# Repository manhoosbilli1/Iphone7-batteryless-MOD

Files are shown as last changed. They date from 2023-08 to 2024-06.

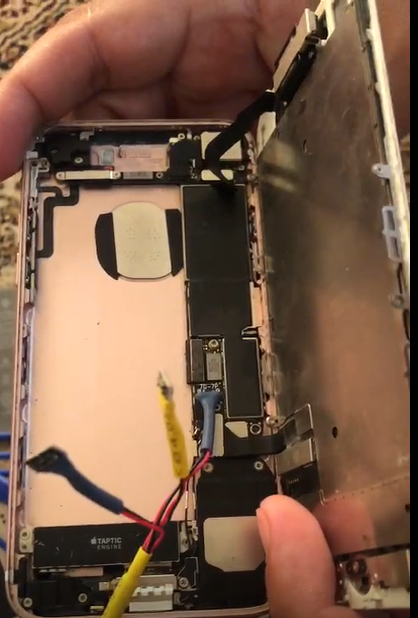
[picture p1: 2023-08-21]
ll.PNG

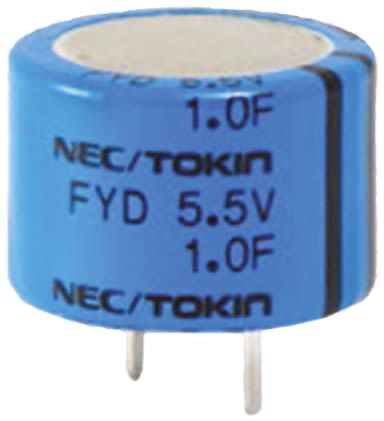
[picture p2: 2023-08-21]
R7897949-01.jpg

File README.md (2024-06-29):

# Iphone7-batteryless-MOD
On going research project into finding a way to use the iphone 7 without a battery like many other smart phones and laptops can be used. 

# Intro
I'm trying to modify iPhone 7 to be able to use without a battery. It's been done before on iPhone 4 successfully and I've seen some people achieve this with iPhone 6. but not iPhone 7 yet. the goal is to revive the old iPhone we have sitting around.

# Problems 
Knowing Apple the thought never crossed my mind that it would as simple as connecting power to the power connector. I was always expecting some kind of logic to be going on behind the scenes. I tried the usual methods of turning on any other android phones but they did not work. 

here is a demo of the current condition of project, [demo](https://youtube.com/shorts/5xmpZtYP9cs?feature=share)

# What I've tried
## Connected power with iPhone battery connector
4.2V line on the battery connector through a stable bench power supply. never turned on. obviously battery was removed at this point. 

## took out the battery protection circuit 
inside the battery and gave it a range of voltage 3.7-4.2V on the terminals where battery is usually attached. never turned on. 

## Used [iboot](https://www.amazon.com/Mechanic-Android-Control-Motherboard-Activation/dp/B07D37CWW3) max+ 

(inspired by qianli ipower max pro (discontinued now [ipower-link](https://www.amazon.com/-/es/Ipower-Pro-Max-reparaci%C3%B3n-compatibles/dp/B0946PBCHP)), it turned on but turns off after 2 minutes. doesn't seem to be a timed event as when computation need increases it turns off. made me think that the device might not be able to provide the surge current it needs compared to when using a battery so, 
[iboot connected to iphone 7][1]
[iboot modul][2]

## added 5V 1F cap across the battery connector with iboot max+ 
similar behaviour as before. turns of after around 2 minutes or before. restarts and so on. no luck 

## Thought to simulate battery while plugged in 
Connected  iboot max+ to iphone and connected charging cable to it's port. the iboot started making noise which made me think that iboot might not expect a reverse current since the battery  connnector also charges it. so that didn't work. 

# Conclusions up till this point 
- there is no circuitry inside a battery anymore so the phones lets iboot max+ power it on and keep it working for a few minutes but it seems like there's a certain communication going on between the battery and the phone. 
- Since it's just a simple battery seems like it's either expecting a certain resistance on the power lines
- Or some kind of response after it uses some of the power from the battery

Nothing else is coming to mind now, i do not have an oscilloscope right now to check the boot power sequence from the battery, though i think that might be helpful. 

  [1]: https://i.stack.imgur.com/8uuAC.png
  [2]: https://i.stack.imgur.com/W1e5v.png

# 8/15/2023 Thoughts 
I am now certain that the battery is designed in a way as to signal the circuit to let it know "hey i'm from apple" usually batteries of samsung and other brands are recognized when the resistance on the power line is of a certain value but this one is more complex. The only way forward now seems to be to simulate a genuine iphone battery via software and hardware. why reinvent the wheel when there is such a thing called Qianli ipower pro max+ but sadly the stock outside of china is most likely used up and no new stock in coming up. now the option is to wait for 30-40 days for the shipment to arrive or to pay extra 100-150$ for faster shipment which is not that fast as it takes between 7 to 15 days. nonetheless i'll now wait for qianli to test it out

# 2/2/2024 Reverse Engineering Qianli
I decided to go with qianli's ipower pro max to use this with. the tests were a success and the results were promising. however the circuit right now is pretty bulky. i'm trying to reverse engineeer that circuit to be able to recreate and fit it into the battery slot of iphone or the back case of iphone without too much added weight.. here's how i started to reverse engineer it. please note the resistor values are wrong but the IC names are correct. Screenshot 2024-02-02 at 2 36 48 AM

# 6/29/2024 Succesfully embedded circuit inside phone
I removed the battery, used the connector for attaching the power and a ground, and one signal wire that is going to communicate the battery discharge parameters to it. I fit the PCB inside phone just barely finding space for the screen to close. For phones with a larger battery this circuit can fit more easily. i'll be upload an update video soon.

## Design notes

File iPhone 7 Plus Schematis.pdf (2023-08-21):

# D11 MLB - PVT

## LAST_MODIFICATION=Wed Jul 6 08:55:26 2016

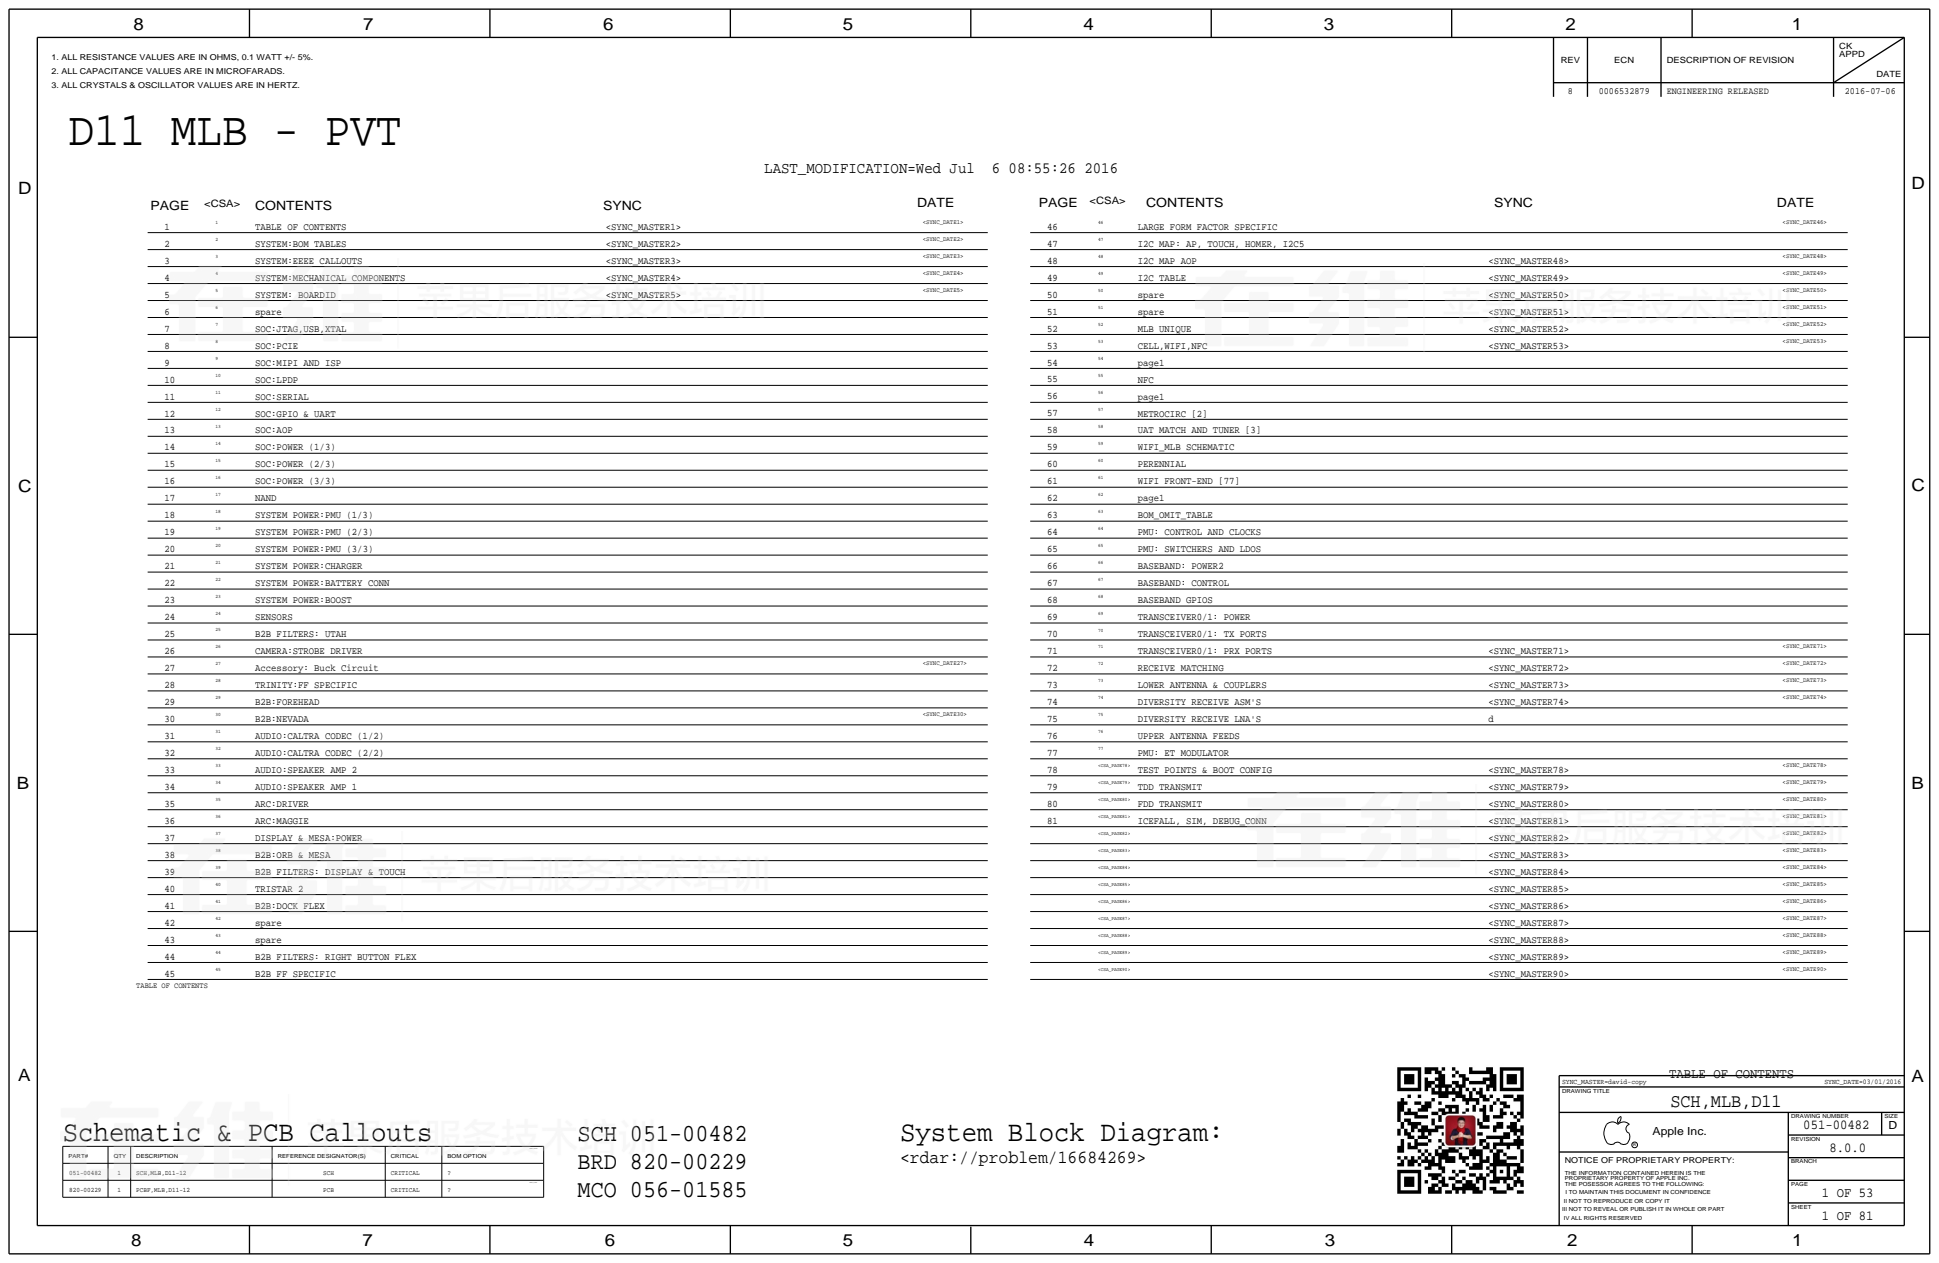
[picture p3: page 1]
MCO 056-01585; BRD 820-00229; SCH 051-00482; System Block Diagram:; <rdar://problem/16684269>; <SYNC_DATE5>; <SYNC_MASTER90>; <SYNC_DATE46>; <SYNC_MASTER71>; <SYNC_MASTER86>; <SYNC_MASTER5>; <SYNC_MASTER4>; <SYNC_DATE27>; <CSA_PAGE90>; <CSA_PAGE89>; <CSA_PAGE88>; <CSA_PAGE87>; <CSA_PAGE86>; <CSA_PAGE85>; <CSA_PAGE84>; <CSA_PAGE83>; <CSA_PAGE80>; <CSA_PAGE81>; <SYNC_DATE4>; <SYNC_DATE1>; <SYNC_MASTER80>; <SYNC_MASTER78>; <SYNC_MASTER82> <SYNC_MASTER83>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

REV | ECN | DESCRIPTION OF REVISION | CK APPD DATE

1. ALL RESISTANCE VALUES ARE IN OHMS, 0.1 WATT +/- 5%.
2. ALL CAPACITANCE VALUES ARE IN MICROFARADS.
3. ALL CRYSTALS & OSCILLATOR VALUES ARE IN HERTZ.

TABLE OF CONTENTS
SYSTEM:BOM TABLES
SYSTEM:EEEE CALLOUTS
SYSTEM:MECHANICAL COMPONENTS
SYSTEM: BOARDID
spare
SOC:JTAG,USB,XTAL
SOC:PCIE
SOC:MIPI AND ISP
SOC:LPDP
SOC:SERIAL
SOC:GPIO & UART
SOC:AOP

LARGE FORM FACTOR SPECIFIC
I2C MAP: AP, TOUCH, HOMER, I2C5
I2C MAP AOP
I2C TABLE
MLB UNIQUE
CELL,WIFI,NFC
page1
NFC
METROCIRC [2]
UAT MATCH AND TUNER [3]
WIFI_MLB SCHEMATIC

SOC:POWER (1/3)
SOC:POWER (2/3)
SOC:POWER (3/3)
NAND
SYSTEM POWER:PMU (1/3)
SYSTEM POWER:PMU (2/3)
SYSTEM POWER:PMU (3/3)
SYSTEM POWER:CHARGER
SYSTEM POWER:BATTERY CONN
SYSTEM POWER:BOOST
SENSORS
B2B FILTERS: UTAH

PERENNIAL
WIFI FRONT-END [77]
BOM_OMIT_TABLE
PMU: CONTROL AND CLOCKS
PMU: SWITCHERS AND LDOS
BASEBAND: POWER2
BASEBAND: CONTROL
BASEBAND GPIOS
TRANSCEIVER0/1: POWER
TRANSCEIVER0/1: TX PORTS
TRANSCEIVER0/1: PRX PORTS

CAMERA:STROBE DRIVER
Accessory: Buck Circuit
TRINITY:FF SPECIFIC
B2B:FOREHEAD
B2B:NEVADA
AUDIO:CALTRA CODEC (1/2)
AUDIO:CALTRA CODEC (2/2)
AUDIO:SPEAKER AMP 2
AUDIO:SPEAKER AMP 1
ARC:DRIVER

RECEIVE MATCHING
LOWER ANTENNA & COUPLERS
DIVERSITY RECEIVE ASM'S
DIVERSITY RECEIVE LNA'S
UPPER ANTENNA FEEDS
PMU: ET MODULATOR
TEST POINTS & BOOT CONFIG
TDD TRANSMIT
FDD TRANSMIT
ICEFALL, SIM, DEBUG_CONN

ARC:MAGGIE
DISPLAY & MESA:POWER
B2B:ORB & MESA
B2B FILTERS: DISPLAY & TOUCH
TRISTAR 2
B2B:DOCK FLEX
B2B FILTERS: RIGHT BUTTON FLEX
B2B FF SPECIFIC

Schematic & PCB Callouts

SCH,MLB,D11

PART# | QTY | DESCRIPTION | REFERENCE DESIGNATOR(S) | CRITICAL | TABLE_5_HEAD BOM OPTION
051-00482 | 1 | SCH,MLB,D11-12 | SCH | CRITICAL | ?

NOTICE OF PROPRIETARY PROPERTY:
THE INFORMATION CONTAINED HEREIN IS THE
PROPRIETARY PROPERTY OF APPLE INC.
THE POSESSOR AGREES TO THE FOLLOWING:
I TO MAINTAIN THIS DOCUMENT IN CONFIDENCE
II NOT TO REPRODUCE OR COPY IT
III NOT TO REVEAL OR PUBLISH IT IN WHOLE OR PART
IV ALL RIGHTS RESERVED

# Global R/C Alternates

# Load Switch OMIT TABLE

# UT LDO Alternates

# Magnesium Alternates

updated 11/12

# Power Inductor Alternates

# Active Diode Alternate

# Global Varistor Alternates

# Global Ferrite Alternates

NAND BOM Options | Acc Buck Alternates

# DDR PLL Alternate

# Mamba LDO Alternates

# I2C5 Alternate

updated 11/12
reverted 11/13

For Chestnut inductor; so it doesn't interfere with PMU inducotr Buck 7 alts

Except BUCK5 LX (BUCK5 LX is Taiyo only)

MUR+KYO 15UF

# N&V 15uF Cap Alternates

CPU

GPU + GPU_SRAM

#22686038:See Radar

8.0.0

051-00482

138S0648 | 138S0652 | ALTERNATE | ALL | CAP,X5R,4.7UF,6.3V,0.65MM,0402,TAIYO
132S0400 | 132S0436 | ALTERNATE | ALL | CAP,X5R,0.22UF,6.3V,01005,TDK
138S00024 | 138S0986 | ALTERNATE | ALL | CAP,CER,3-TERM,7.5UF,20%,4V,0402,TAIYO/TDK
138S0945 | 138S0739 | ALTERNATE | ALL | CAP,CER,1UF,20%,10V,X5R,0201,KYOCERA
138S00005 | 138S00003 | ALTERNATE | (C1813, C1820, C1827) | CAP,X5R,15UF,6.3V,0.65MM,0402,TY
138S00005 | 138S00003 | ALTERNATE | (C1838, C1843, C1845) | CAP,X5R,15UF,6.3V,0.65MM,0402,TY
138S00005 | 138S00003 | ALTERNATE | (C1819, C1826, C1832) | CAP,X5R,15UF,6.3V,0.65MM,0402,TY
132S0436 | 132S0400 | ALTERNATE | ALL | CAP,CER,X5R,0.22UF,20%,6.3V,20%
SYNC_MASTER=Sync | SYNC_DATE=06/29/2016

## SYSTEM:BOM TABLES

138S00006 | 138S0835 | ALTERNATE | ALL | CAP, 3-TERM, 4.3UF, 4V, 0402
138S0702 | 138S0657 | ALTERNATE | ALL | CAP, X5R, 4.3UF, 4V, 0610
138S0706 | 138S0739 | ALTERNATE | ALL | CAP,CER,1UF,20%,10V,X5R,0201,MURATA
118S0764 | 118S0717 | ALTERNATE | ALL | RES, 3.92K, 0.1%, 0201
376S00106 | 376S00047 | ALTERNATE | Q2101 | DIODES INC. ACT DIODE
335S00234 | 335S00233 | ALTERNATE | U1101 | I2C5 ALTERNATE
138S00048 | 138S00003 | ALTERNATE | ALL | CAP,X5R,15UF,6.3V,0.65MM,0402,KYOCERA
138S00005 | 138S00003 | ALTERNATE | (C1834, C1866, C1414) | CAP,X5R,15UF,6.3V,0.65MM,0402,TY
138S00005 | 138S00003 | ALTERNATE | (C1814, C1821, C1828) | CAP,X5R,15UF,6.3V,0.65MM,0402,TY
138S00005 | 138S00003 | ALTERNATE | (C1833, C1839, C1865) | CAP,X5R,15UF,6.3V,0.65MM,0402,TY
138S00005 | 138S00003 | ALTERNATE | (C1401, C1408, C1434) | CAP,X5R,15UF,6.3V,0.65MM,0402,TY
138S00005 | 138S00003 | ALTERNATE | (C1837, C1842, C1844) | CAP,X5R,15UF,6.3V,0.65MM,0402,TY
138S00005 | 138S00003 | ALTERNATE | (C1806, C1810) | CAP,X5R,15UF,6.3V,0.65MM,0402,TY
335S00169 | 1 | NAND,H,32GB,16nm,MLC | U1701 | CRITICAL | TABLE_5_ITEM NAND_32G
335S00182 | 1 | NAND,H,128GB,16nm,TLC | U1701 | CRITICAL | TABLE_5_ITEM NAND_128G
335S00183 | 1 | NAND,T,256GB,3Dv3,TLC | U1701 | CRITICAL | TABLE_5_ITEM NAND_256G
138S0867 | 5 | CAP,X5R,10UF,20%,6.3V,0.65MM,HRZTL,0402 | C1748,C1713,C1716,C1721,C1733 | CRITICAL | TABLE_5_ITEM NAND_32G
138S00003 | 5 | CAP,X5R,15UF,20%,,6.3V,0.65MM,HRZTL,0402 | C1748,C1713,C1716,C1721,C1733 | CRITICAL | TABLE_5_ITEM NAND_128G
138S00003 | 5 | CAP,X5R,15UF,20%,,6.3V,0.65MM,HRZTL,0402 | C1748,C1713,C1716,C1721,C1733 | CRITICAL | TABLE_5_ITEM NAND_256G
PART NUMBER | ALTERNATE FOR PART NUMBER | BOM OPTION | REF DES | TABLE_ALT_HEAD COMMENTS:
335S00201 | 335S00169 | ALTERNATE | U1701 | T,15nm,MLC,32GB
335S00209 | 335S00169 | ALTERNATE | U1701 | TABLE_ALT_ITEM S,16nm,MLC,32GB
335S00195 | 335S00182 | ALTERNATE | U1701 | TABLE_ALT_ITEM SS,1Ynm,TLC,128GB
335S00180 | 335S00182 | ALTERNATE | U1701 | TABLE_ALT_ITEM T,15nm,TLC,128GB
335S00179 | 335S00182 | ALTERNATE | U1701 | TABLE_ALT_ITEM SD,15nm,TLC,128GB
335S00148 | 335S00183 | ALTERNATE | U1701 | TABLE_ALT_ITEM SD,3Dv2,TLC,256GB
335S00190 | 335S00183 | ALTERNATE | U1701 | TABLE_ALT_ITEM SS,3Dv3,TLC,256GB

TABLE_ALT_ITEM

TABLE_ALT_ITEM

TABLE_ALT_ITEM

TABLE_ALT_ITEM

TABLE_ALT_ITEM

TABLE_ALT_ITEM

TABLE_ALT_ITEM

PART NUMBER | ALTERNATE FOR PART NUMBER | BOM OPTION | REF DES | TABLE_ALT_HEAD COMMENTS:

TABLE_ALT_ITEM

PART# | QTY | DESCRIPTION | REFERENCE DESIGNATOR(S) | CRITICAL | TABLE_5_HEAD BOM OPTION
353S01007 | 1 | ONSEMI,IC,LOAD,SWITCH,WLCSP4 | U2710,NFCSW_RF | CRITICAL | TABLE_5_ITEM

REVISION

DRAWING NUMBER | SIZE
D

R

PAGE TITLE

C

A

D

A

B

C

8 | 7 | 6 | 5 | 4 | 3

D

B

8 | 7 | 5 | 4 | 2 | 1

Apple Inc.

PART NUMBER | ALTERNATE FOR PART NUMBER | BOM OPTION | REF DES | TABLE_ALT_HEAD COMMENTS:
371S00087 | 371S00064 | ALTERNATE | D2700 | TABLE_ALT_ITEM DIODE,SHOTTKY,30V,200MA,0201
152S00558 | 152S00557 | ALTERNATE | L2700 | TABLE_ALT_ITEM IND,MLD,0.47UH,2.5A,80Mohm,1608
376S00166 | 376S00164 | ALTERNATE | Q2700,Q2701 | TABLE_ALT_ITEM PFET,12V,CSP4
PART NUMBER | ALTERNATE FOR PART NUMBER | BOM OPTION | REF DES | TABLE_ALT_HEAD COMMENTS:
377S0168 | 377S0140 | ALTERNATE | ALL | TABLE_ALT_ITEM VARISTOR, 6.8V, 100PF, 01005

TABLE_ALT_ITEM

TABLE_ALT_ITEM

TABLE_ALT_ITEM

TABLE_ALT_ITEM

PART NUMBER | ALTERNATE FOR PART NUMBER | BOM OPTION | REF DES | TABLE_ALT_HEAD COMMENTS:
155S00067 | 155S0581 | ALTERNATE | ALL | TABLE_ALT_ITEM FERR, 240OHM, 0.38OHM DCR, 0201
155S0581 | 155S00067 | ALTERNATE | ALL | TABLE_ALT_ITEM FERR, 240OHM, 0.38OHM DCR, 0201
155S00012 | 155S00168 | ALTERNATE | ALL | TABLE_ALT_ITEM FLTR, 65 OHMS, 0605
155S00194 | 155S0610 | ALTERNATE | ALL | TABLE_ALT_ITEM FERR BD, 150OHM, TDK
155S00200 | 155S0610 | ALTERNATE | ALL | TABLE_ALT_ITEM FERR BD, 150OHM, TY
152S00489 | 152S00456 | ALTERNATE | ALL | TABLE_ALT_ITEM FERR BD, 0.47UH, TY

TABLE_ALT_ITEM

PART NUMBER | ALTERNATE FOR PART NUMBER | BOM OPTION | REF DES | TABLE_ALT_HEAD COMMENTS:
338S00173 | 338S00203 | ALTERNATE | U2402 | TABLE_ALT_ITEM Larger Wafer (-29 flow) Magnesium
PART NUMBER | ALTERNATE FOR PART NUMBER | BOM OPTION | REF DES | TABLE_ALT_HEAD COMMENTS:
353S00889 | 353S00015 | ALTERNATE | U2501 | TABLE_ALT_ITEM ST, LDO REG, 2.925V, CSP 0.65x0.65

TABLE_ALT_ITEM

TABLE_ALT_HEAD
PART NUMBER | ALTERNATE FOR | BOM OPTION | REF DES | COMMENTS:
| PART NUMBER
PART NUMBER | ALTERNATE FOR PART NUMBER | BOM OPTION | REF DES | TABLE_ALT_HEAD COMMENTS:
353S00932 | 353S00576 | ALTERNATE | U3801 | TABLE_ALT_ITEM ST, LDO REG, 2.75V

TABLE_ALT_HEAD
PART NUMBER | ALTERNATE FOR | BOM OPTION | REF DES | COMMENTS:
| PART NUMBER
PART NUMBER | ALTERNATE FOR PART NUMBER | BOM OPTION | REF DES | TABLE_ALT_HEAD COMMENTS:
155S00095 | 155S00068 | ALTERNATE | FL1501 | TABLE_ALT_ITEM FERR BD,100OHM,25%,100MA,2OHM,01005
PART NUMBER | ALTERNATE FOR PART NUMBER | BOM OPTION | REF DES | TABLE_ALT_HEAD COMMENTS:
152S00118 | 152S00075 | ALTERNATE | ALL | TABLE_ALT_ITEM IND,PWR,SHLD,1.2 UH,3.0A,0.080 OHM,2016
152S00077 | 152S00397 | ALTERNATE | ALL | TABLE_ALT_ITEM IND,PWR,SHLD,1.0 UH,2.25A,0.150 OHM,2016
152S00121 | 152S00081 | ALTERNATE | ALL | TABLE_ALT_ITEM IND,PWR,SHLD,0.47 UH,3.8A,0.048 OHM,2012
152S00123 | 152S1936 | ALTERNATE | ALL | TABLE_ALT_ITEM IND,PWR,SHLD,15 UH,0.72A,0.900 OHM,3225
152S00402 | 152S00366 | ALTERNATE | ALL | TABLE_ALT_ITEM IND,MULT,1UH,1.2A,0.320 OHM,0603
152S00297 | 152S1843 | ALTERNATE | ALL | TABLE_ALT_ITEM CYNTEC 2012 1UH
152S00365 | 152S00297 | ALTERNATE | ALL | TABLE_ALT_ITEM CYNTEC 2012 1UH
152S00398 | 152S00204 | ALTERNATE | ALL | TABLE_ALT_ITEM IND,PWR,0.22UH,20%,6.7a,23MOHM,2012
152S00120 | 152S00077 | ALTERNATE | ALL | TABLE_ALT_ITEM For Chestnut inductor only
152S00117 | 152S00074 | ALTERNATE | L1806,L1810,L1814,L1816,L1817 | TABLE_ALT_ITEM IND,PWR,SHLD,1.0 UH,3.0A,0.060 OHM,2016

TABLE_ALT_ITEM

TABLE_ALT_ITEM

TABLE_ALT_ITEM

TABLE_ALT_ITEM

TABLE_ALT_ITEM

PART NUMBER | ALTERNATE FOR PART NUMBER | BOM OPTION | REF DES | TABLE_ALT_HEAD COMMENTS:
138S00005 | 138S00003 | ALTERNATE | (C1818, C1825, C1831) | TABLE_ALT_ITEM CAP,X5R,15UF,6.3V,0.65MM,0402,TY

TABLE_ALT_ITEM

TABLE_ALT_ITEM

PART# | QTY | DESCRIPTION | REFERENCE DESIGNATOR(S)

TABLE_5_HEAD
CRITICAL | BOM OPTION

# D11 EEEE CALLOUTS

# CAYMAN DDR Alternates

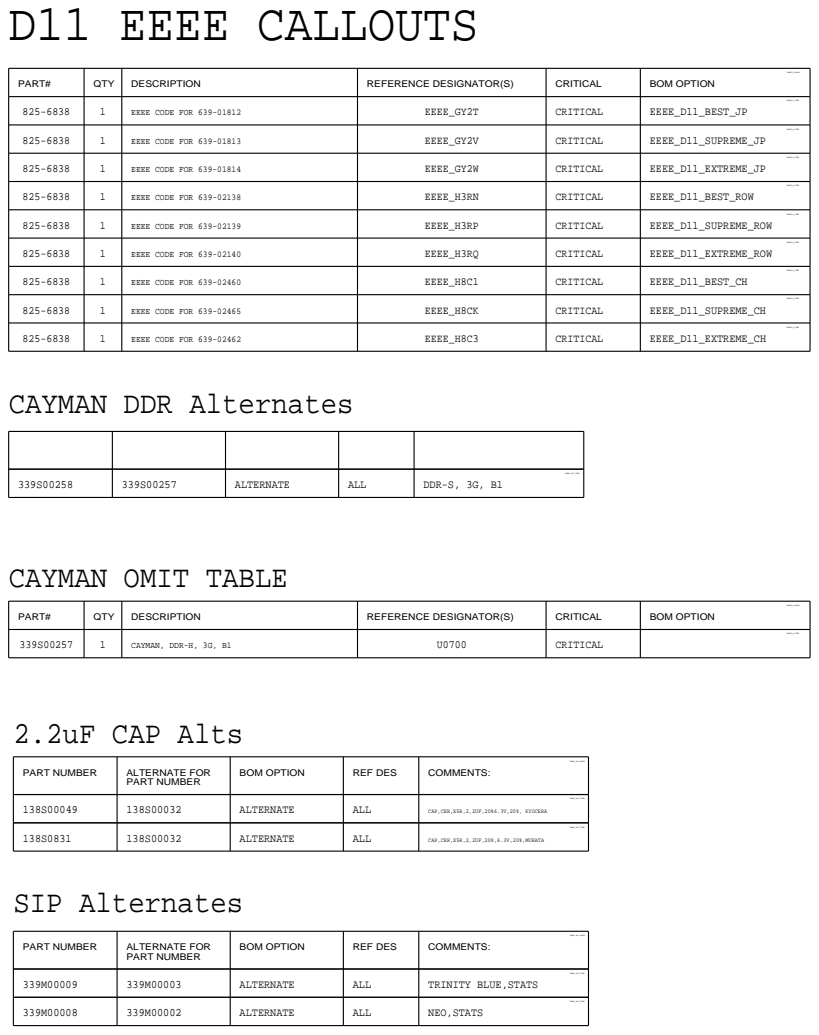
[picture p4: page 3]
2.2uF CAP Alts; SIP Alternates; SYNC_MASTER=david-copy; SYNC_DATE=03/01/2016; ALL; DDR-S, 3G, B1; ALTERNATE; REVISION; DRAWING NUMBER; SIZE; Apple Inc.; TABLE_ALT_ITEM

PART# | QTY | DESCRIPTION | REFERENCE DESIGNATOR(S) | CRITICAL | TABLE_5_HEAD BOM OPTION
825-6838 | 1 | EEEE CODE FOR 639-01812 | EEEE_GY2T | CRITICAL | TABLE_5_ITEM EEEE_D11_BEST_JP
825-6838 | 1 | EEEE CODE FOR 639-01813 | EEEE_GY2V | CRITICAL | TABLE_5_ITEM EEEE_D11_SUPREME_JP
825-6838 | 1 | EEEE CODE FOR 639-01814 | EEEE_GY2W | CRITICAL | TABLE_5_ITEM EEEE_D11_EXTREME_JP
825-6838 | 1 | EEEE CODE FOR 639-02138 | EEEE_H3RN | CRITICAL | TABLE_5_ITEM EEEE_D11_BEST_ROW
825-6838 | 1 | EEEE CODE FOR 639-02139 | EEEE_H3RP | CRITICAL | TABLE_5_ITEM EEEE_D11_SUPREME_ROW
825-6838 | 1 | EEEE CODE FOR 639-02140 | EEEE_H3RQ | CRITICAL | TABLE_5_ITEM EEEE_D11_EXTREME_ROW
825-6838 | 1 | EEEE CODE FOR 639-02460 | EEEE_H8C1 | CRITICAL | TABLE_5_ITEM EEEE_D11_BEST_CH
825-6838 | 1 | EEEE CODE FOR 639-02465 | EEEE_H8CK | CRITICAL | TABLE_5_ITEM EEEE_D11_SUPREME_CH
825-6838 | 1 | EEEE CODE FOR 639-02462 | EEEE_H8C3 | CRITICAL | TABLE_5_ITEM EEEE_D11_EXTREME_CH

CAYMAN OMIT TABLE

339S00257 | 1 | CAYMAN, DDR-H, 3G, B1 | U0700 | CRITICAL | TABLE_5_ITEM

PART NUMBER | ALTERNATE FOR PART NUMBER | BOM OPTION | REF DES | TABLE_ALT_HEAD COMMENTS:

138S00049 | 138S00032 | ALTERNATE | ALL | TABLE_ALT_ITEM CAP,CER,X5R,2,2UF,20%6.3V,20%, KYOCERA

138S0831 | 138S00032 | ALTERNATE | ALL | TABLE_ALT_ITEM CAP,CER,X5R,2,2UF,20%,6.3V,20%,MURATA

339M00009 | 339M00003 | ALTERNATE | ALL | TABLE_ALT_ITEM TRINITY BLUE,STATS
339M00008 | 339M00002 | ALTERNATE | ALL | TABLE_ALT_ITEM NEO,STATS

PAGE TITLE
SYSTEM:EEEE CALLOUTS

# Current as of D11 MCO 056-01585 rev. 63

O

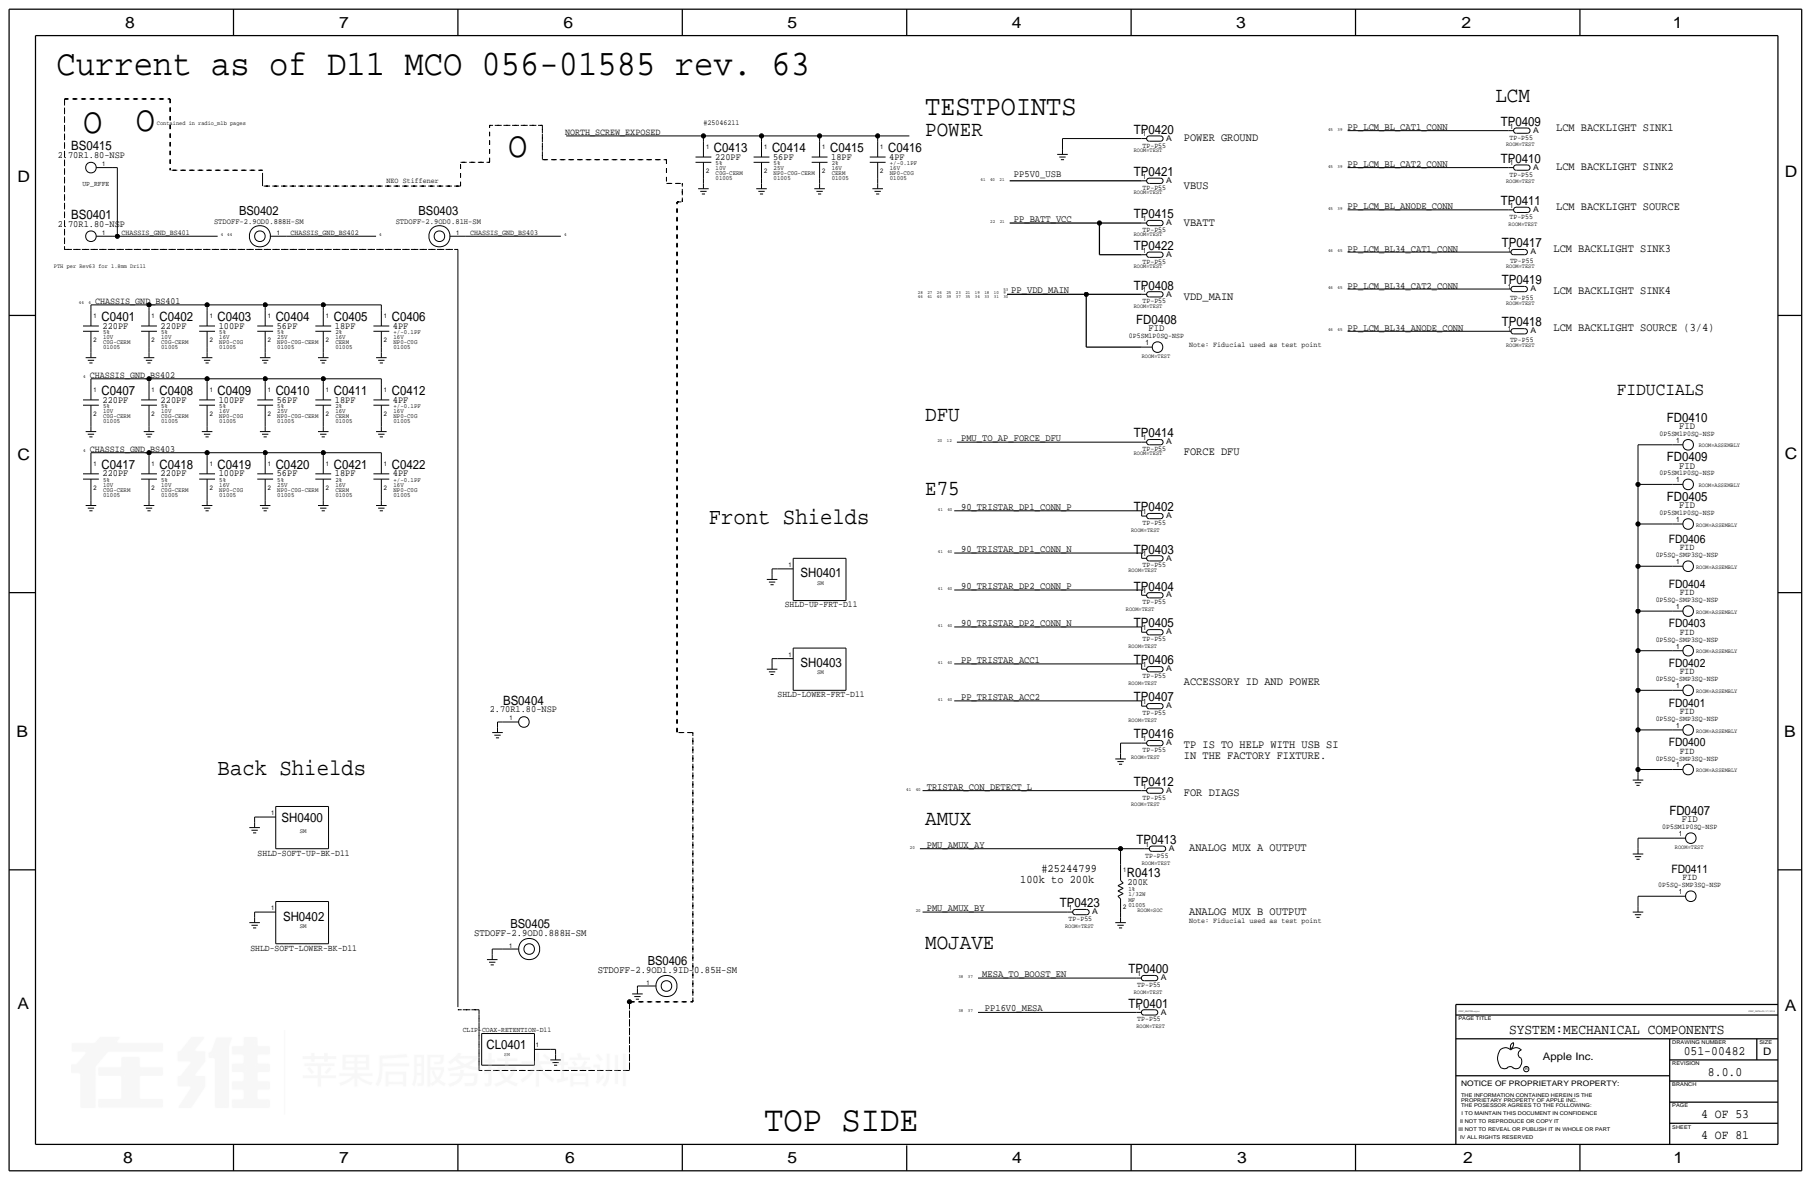
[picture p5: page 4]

PTH per Rev63 for 1.8mm Drill

220PF CHASSIS_GND_BS402 | 220PF | 100PF | 56PF | 18PF

Note: Fiducial used as test point

220PF CHASSIS_GND_BS403 | 220PF | 100PF | 56PF | 18PF

ANALOG MUX B OUTPUT

SHLD-SOFT-LOWER-BK-D11

# BOARD ID BOOT CONFIG

0=MLB, 1=DEV
0=FORM FACTOR A, 1=FORM FACTOR B
0=EUREKA, 1=KAROO

BOOT_CONFIG[2:0]
FLOAT=LOW, PULLUP=HIGH

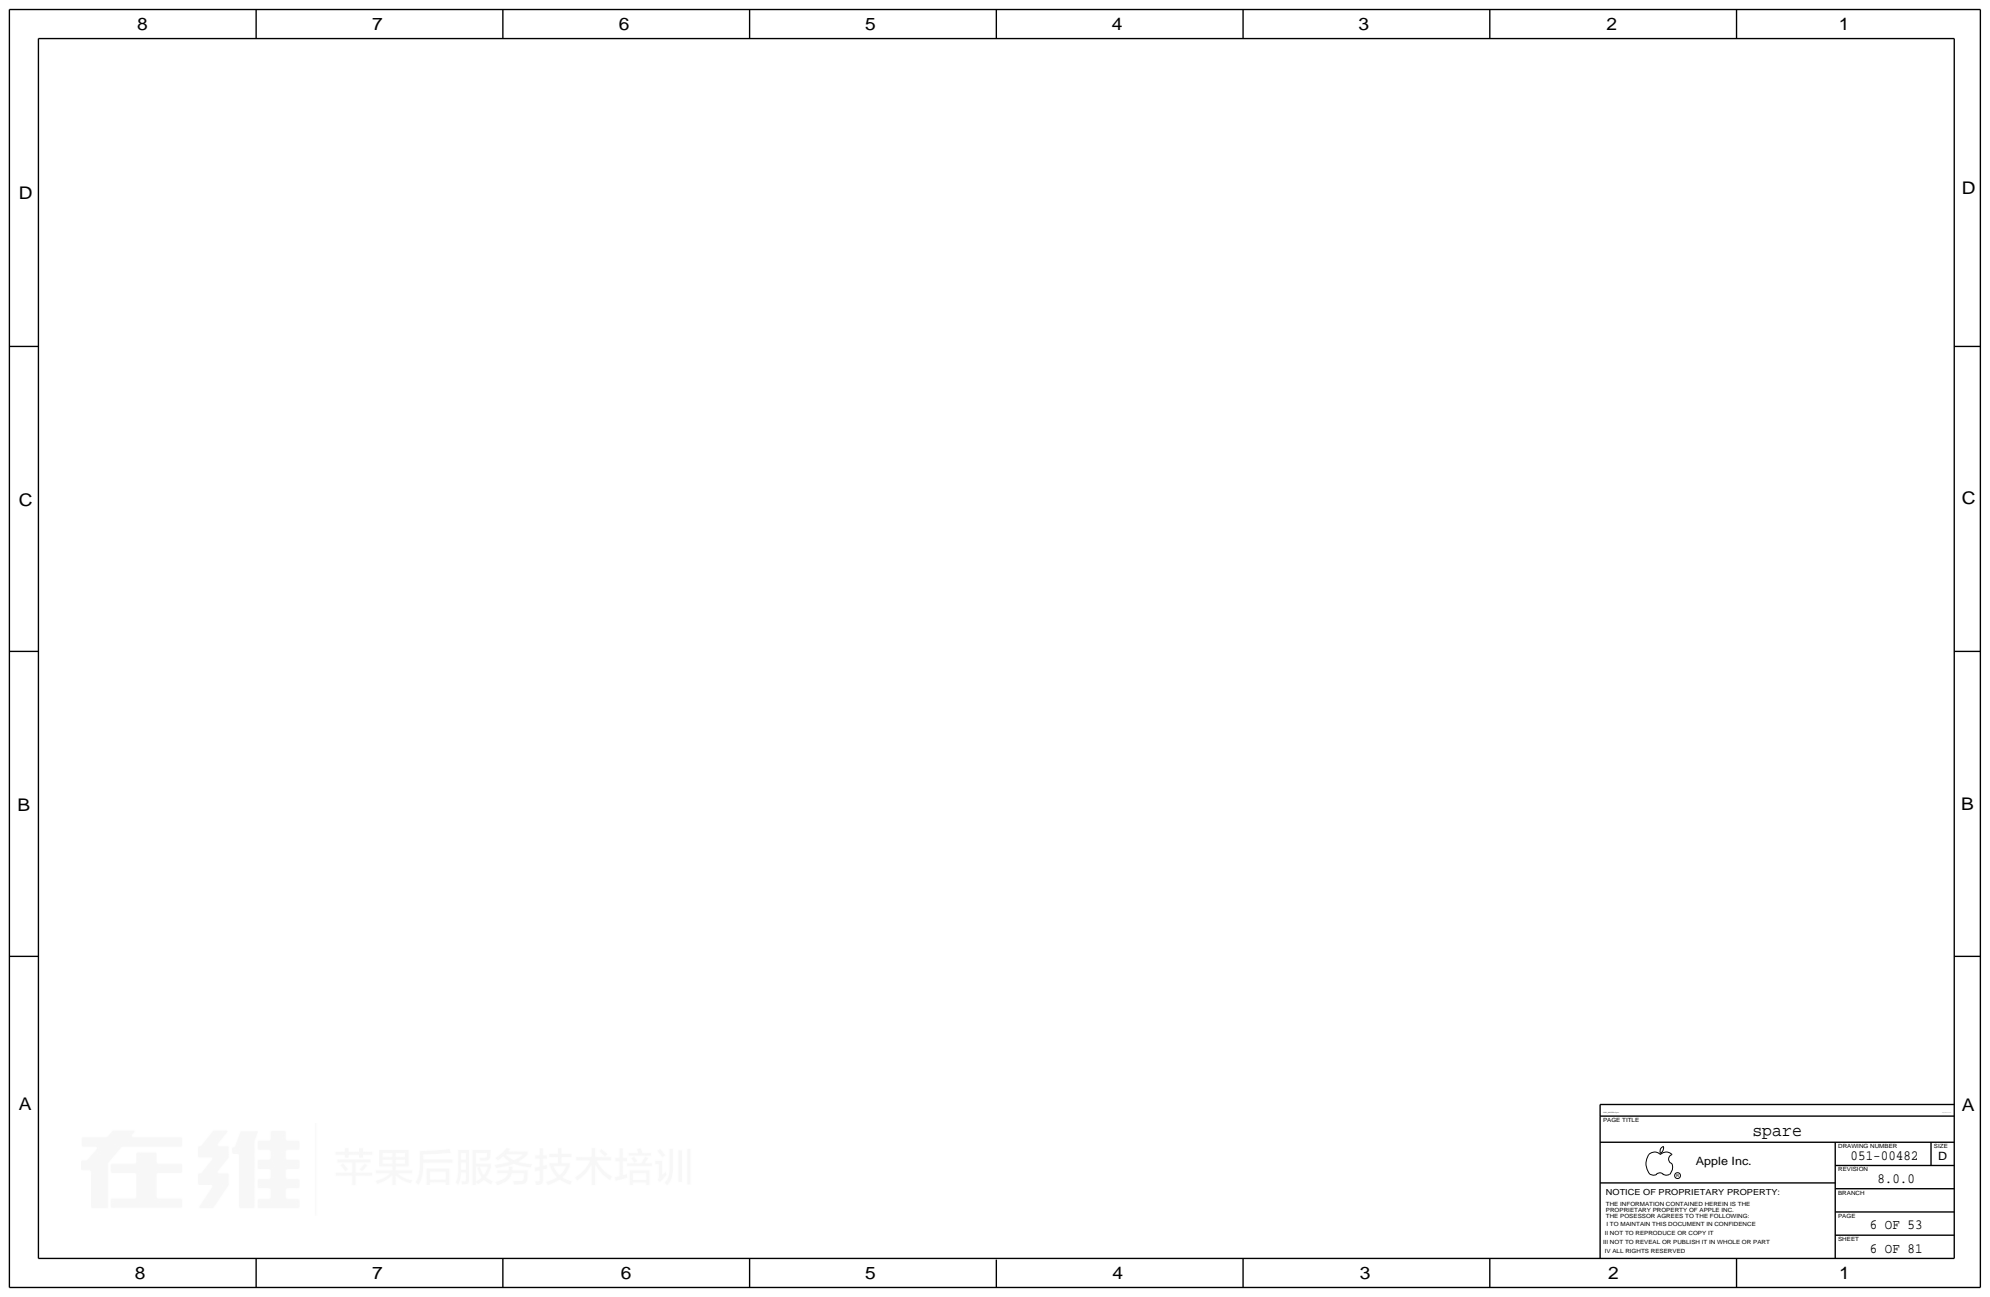
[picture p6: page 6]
spare; SYNC_MASTER=Sync; SYNC_DATE=06/06/2016; REVISION; DRAWING NUMBER; SIZE; PAGE TITLE; Apple Inc.

VDD11_XTAL:1.06-1.17V @TBD mA MAX

tbd - tbd V @5mA MAX

SOC:JTAG,USB,XTAL

# SOC - PCIE INTERFACES

# SYM 2 OF 16 VDD_FIXED_PCIE_CLK

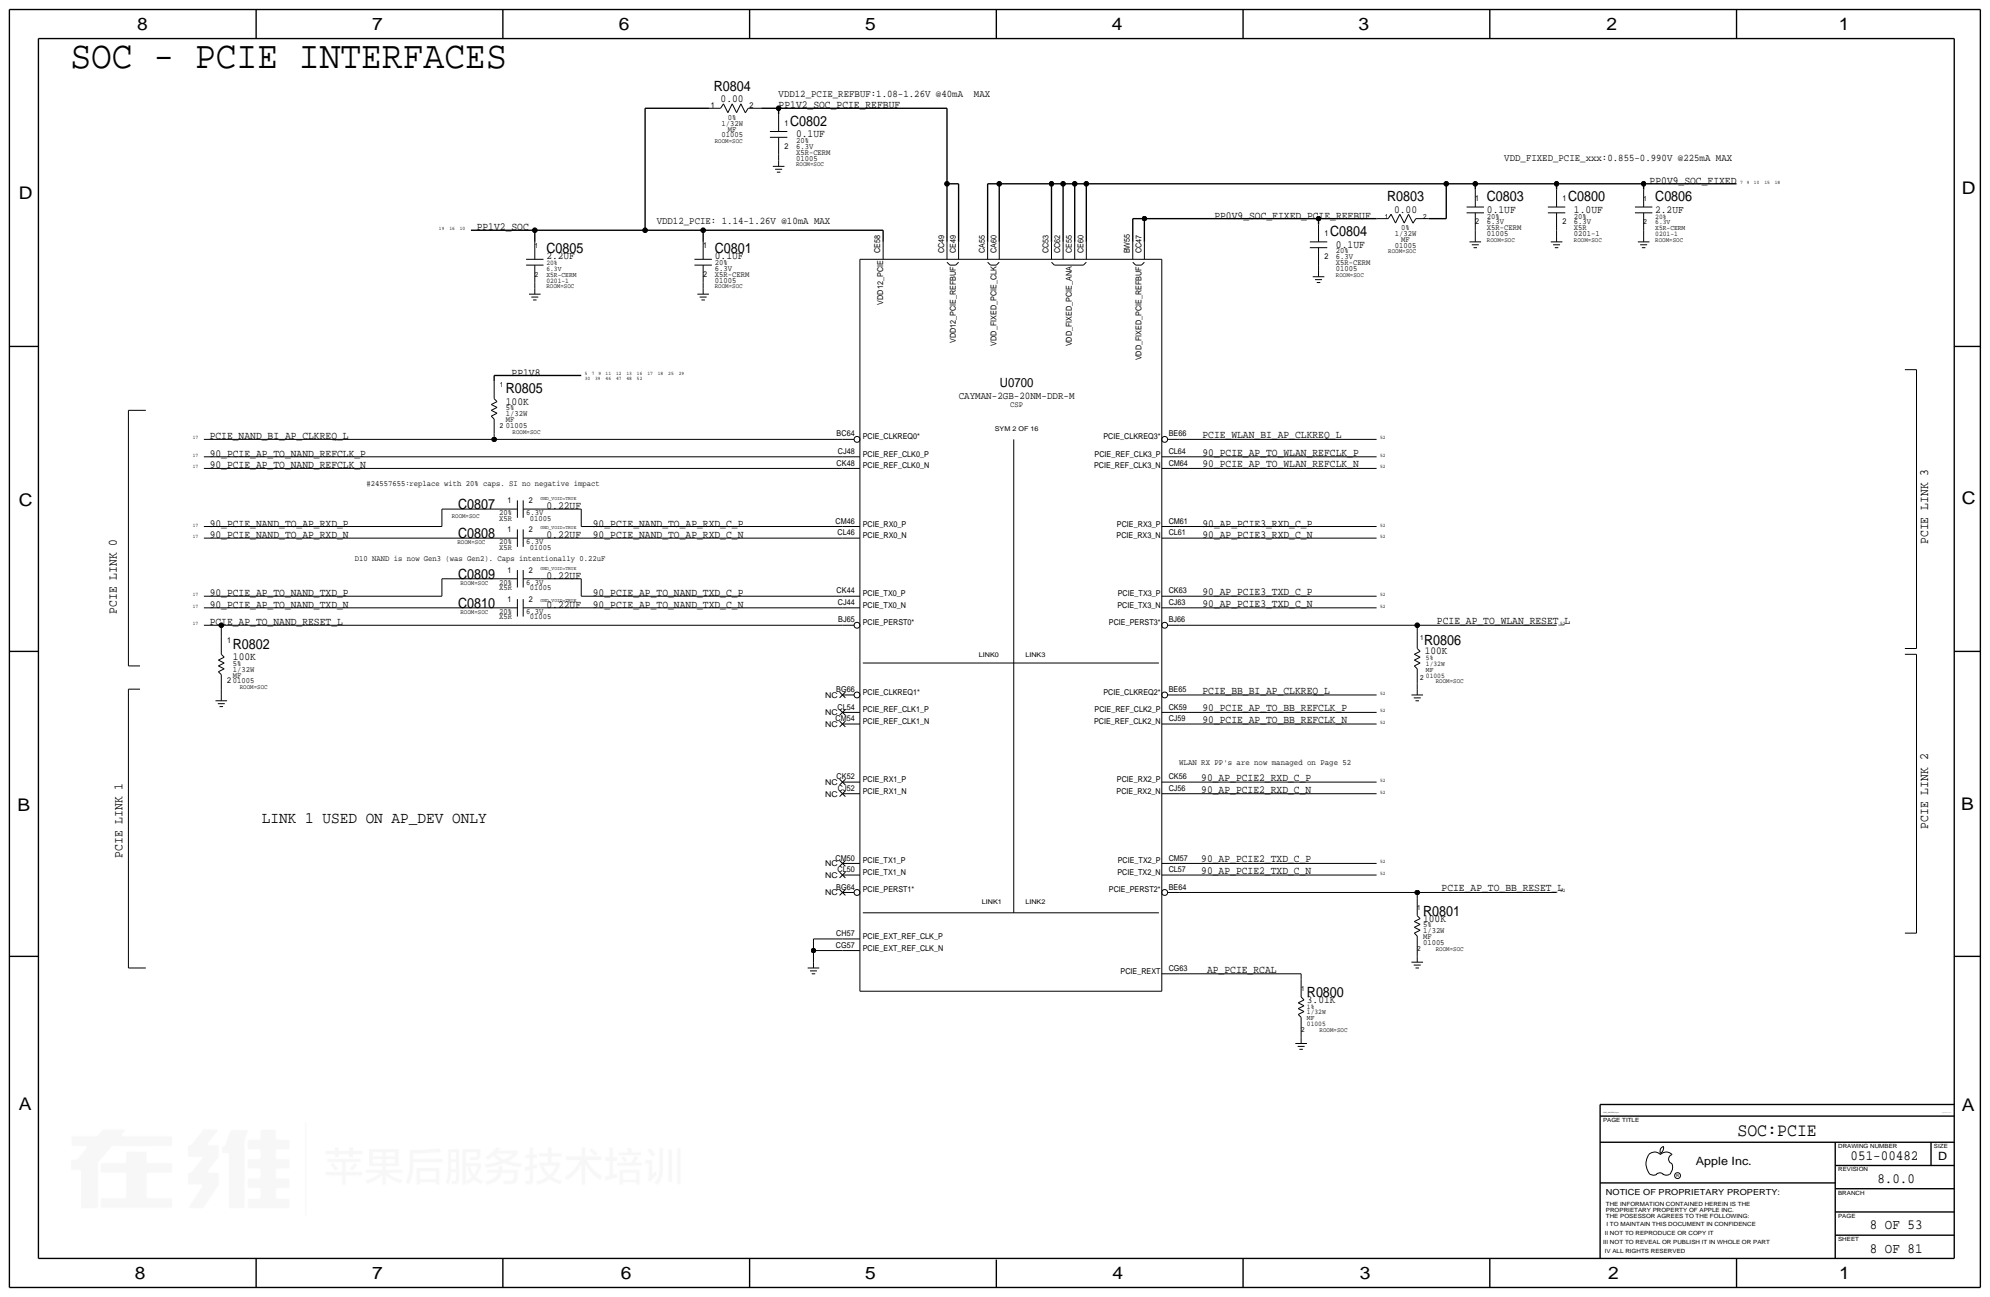
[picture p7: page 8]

PCIE LINK 2 PCIE LINK 3

#24557655:replace with 20% caps. SI no negative impact

PCIE LINK 0 PCIE LINK 1

D10 NAND is now Gen3 (was Gen2). Caps intentionally 0.22uF

LINK 1 USED ON AP_DEV ONLY

# SOC - MIPI & ISP INTERFACES

# 1 C0910 G¹³ G¹⁷ G⁶

Radar 20511449
<--- Needed for Cayman debug; this pin cannot be input

SOC:MIPI AND ISP

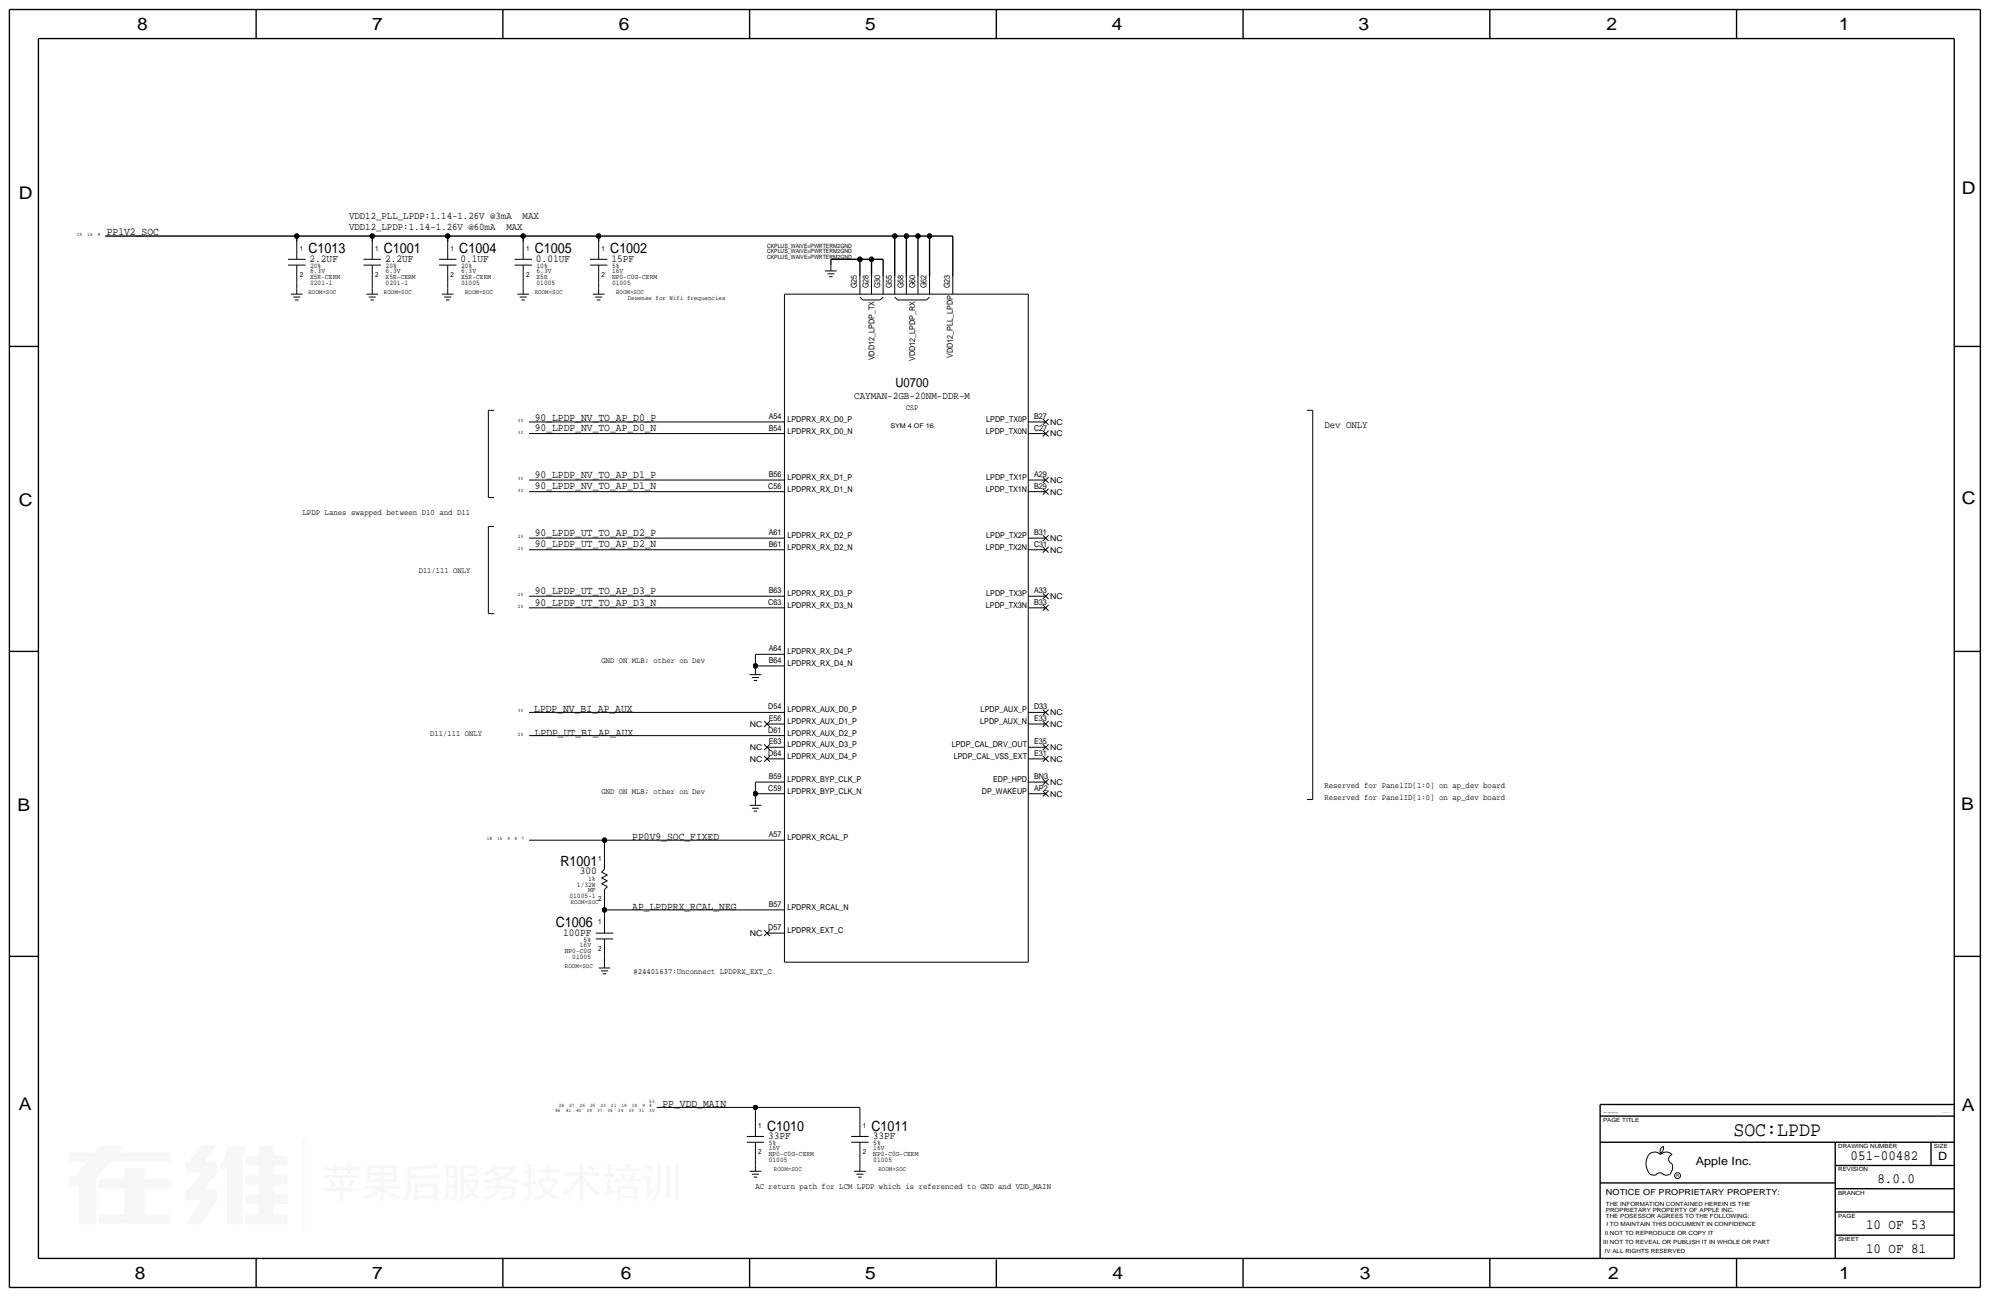
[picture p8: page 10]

LPDP Lanes swapped between D10 and D11

GND ON MLB; other on Dev

Reserved for PanelID[1:0] on ap_dev board

# SOC - SERIAL INTERFACES

SPI_AP_TO_CODEC_MAGGIE_SCLK
Route as daisy-chain. No T's allowed.

See Radar#25316444 for Details

# SOC - GPIO INTERFACES

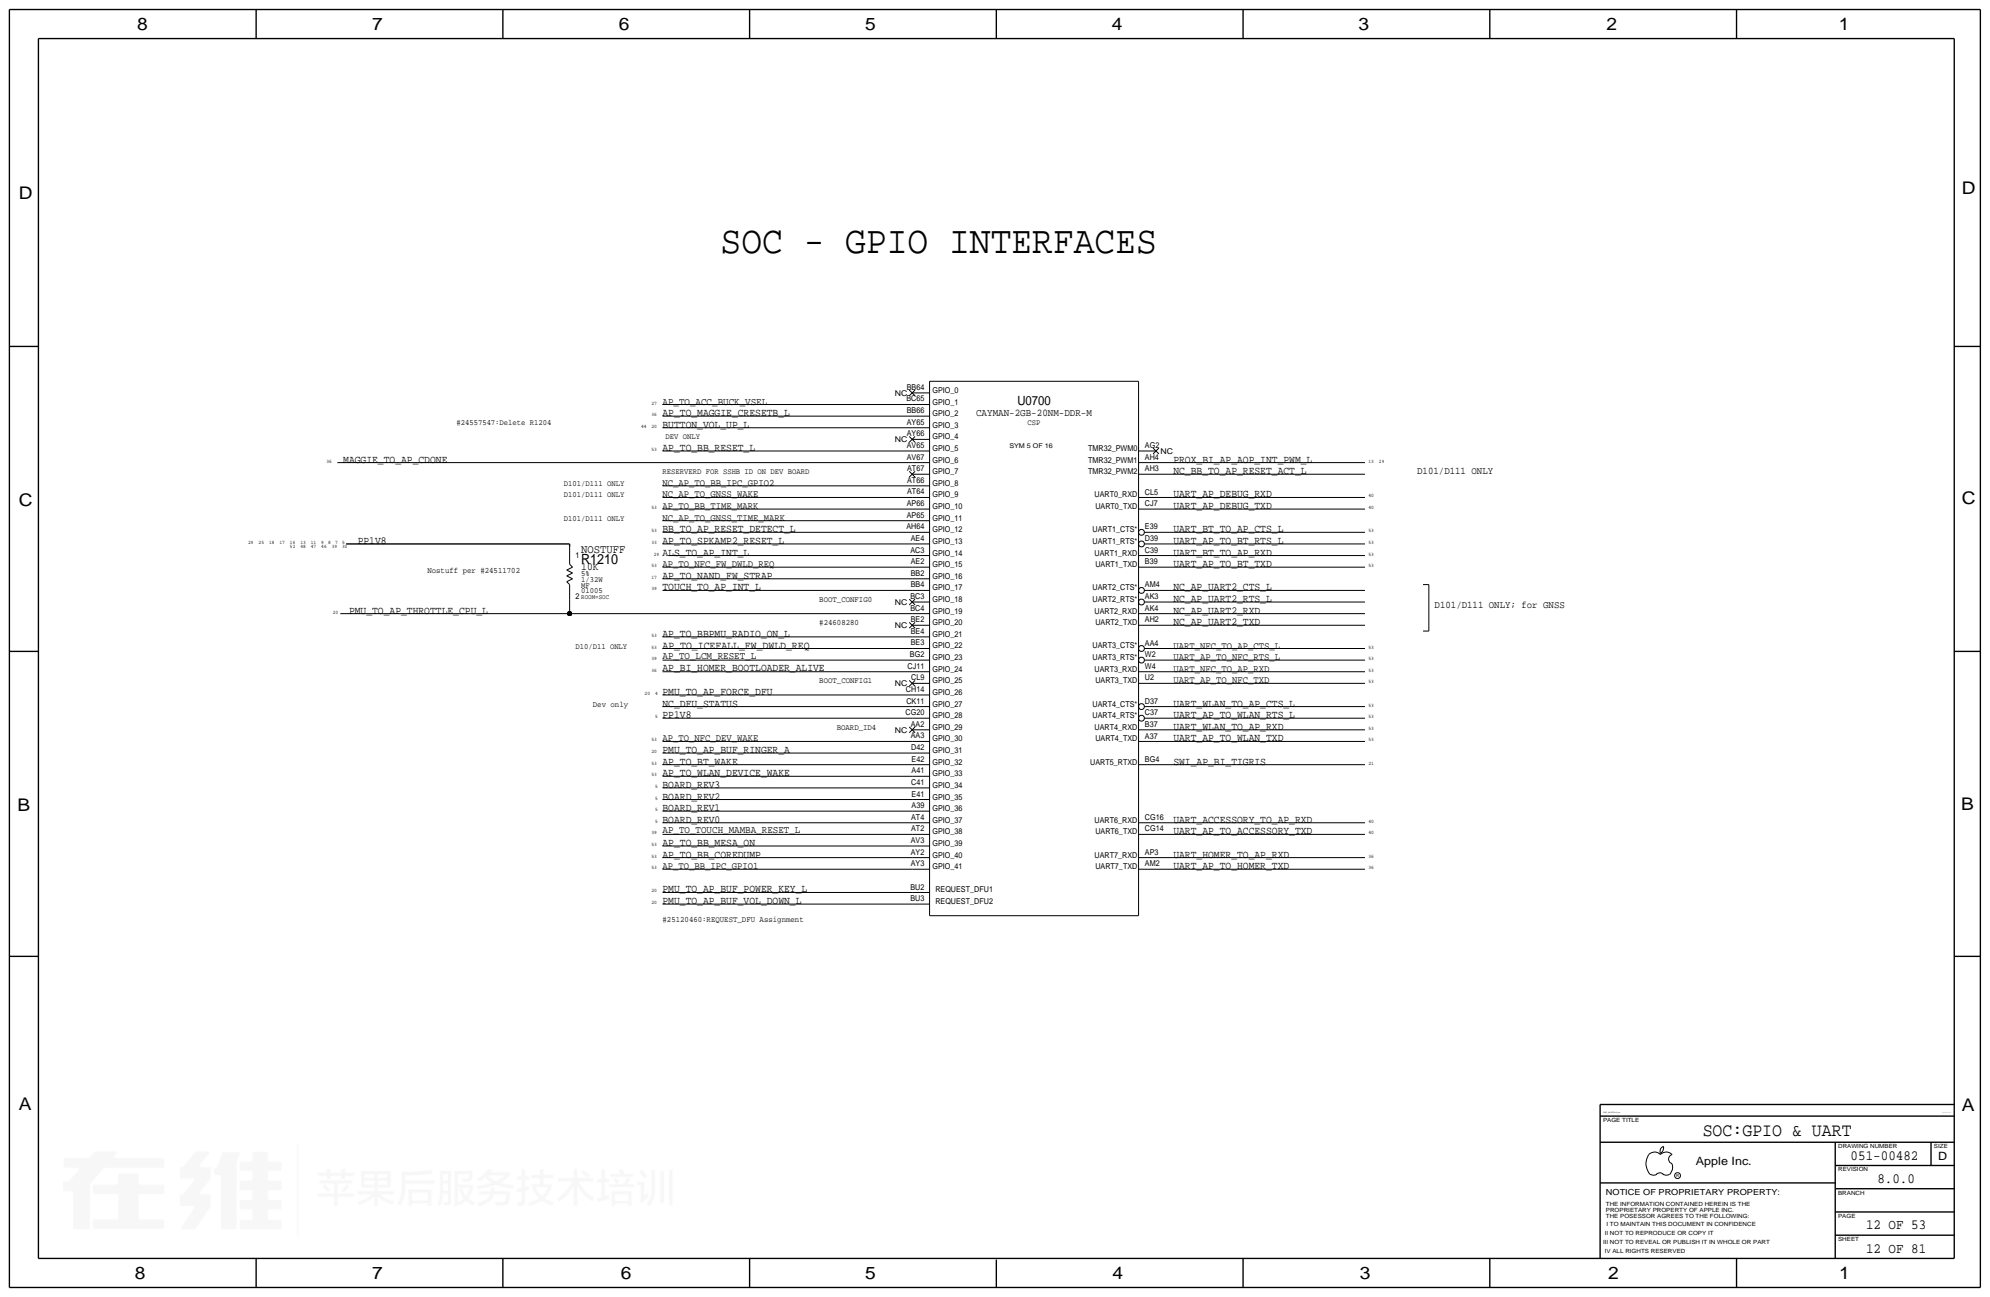
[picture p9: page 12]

# SOC - AOP

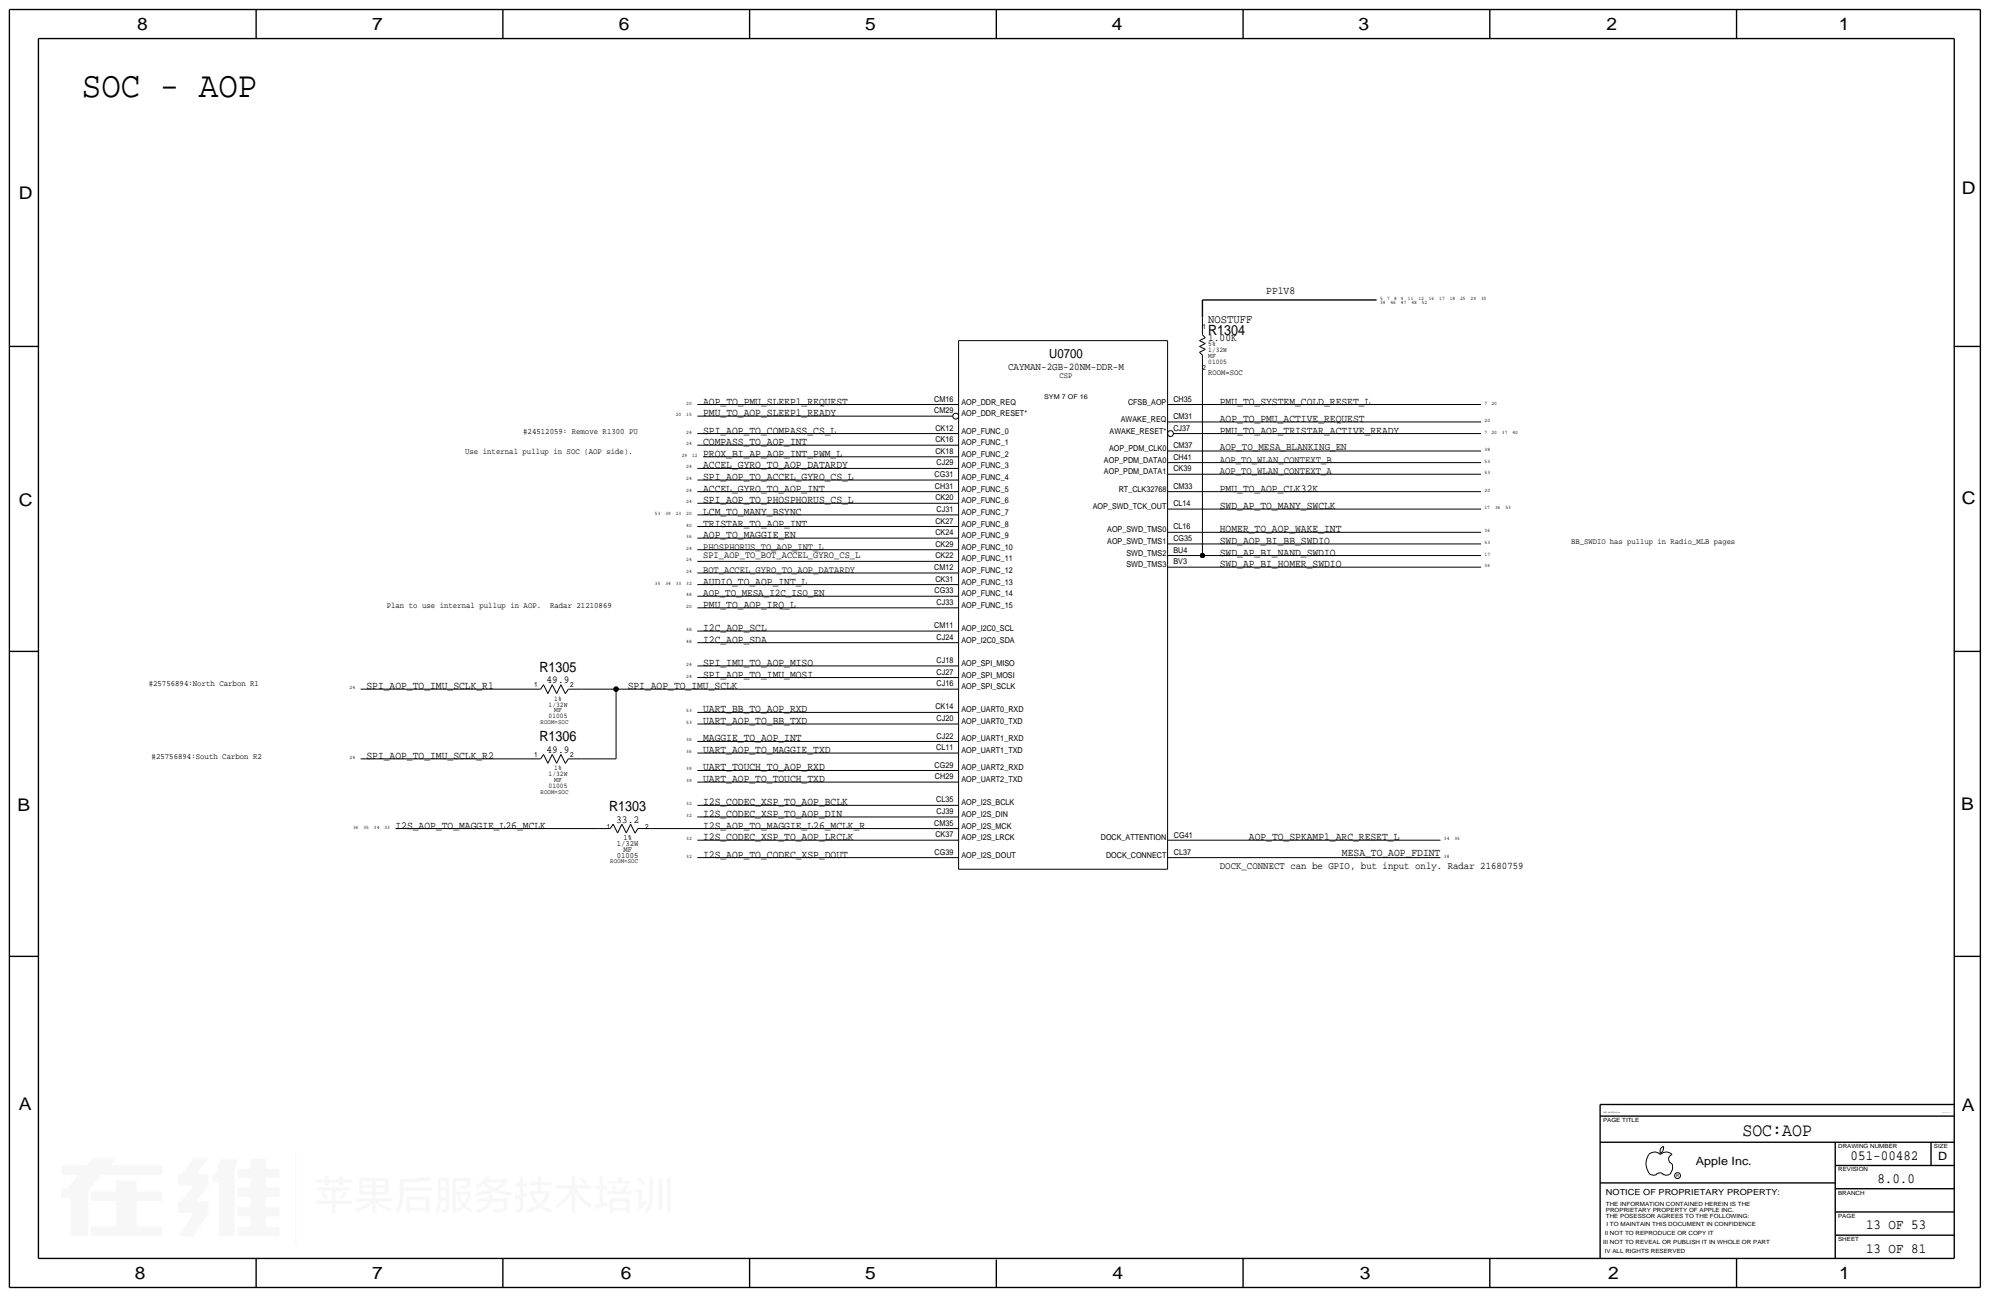
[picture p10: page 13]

Use internal pullup in SOC (AOP side).

BB_SWDIO has pullup in Radio_MLB pages

Plan to use internal pullup in AOP. Radar 21210869

AOP_TO_SPKAMP1_ARC_RESET_L
DOCK_CONNECT can be GPIO, but input only. Radar 21680759

# SOC - CPU, GPU & SOC RAILS

# SOC - POWER SUPPLIES

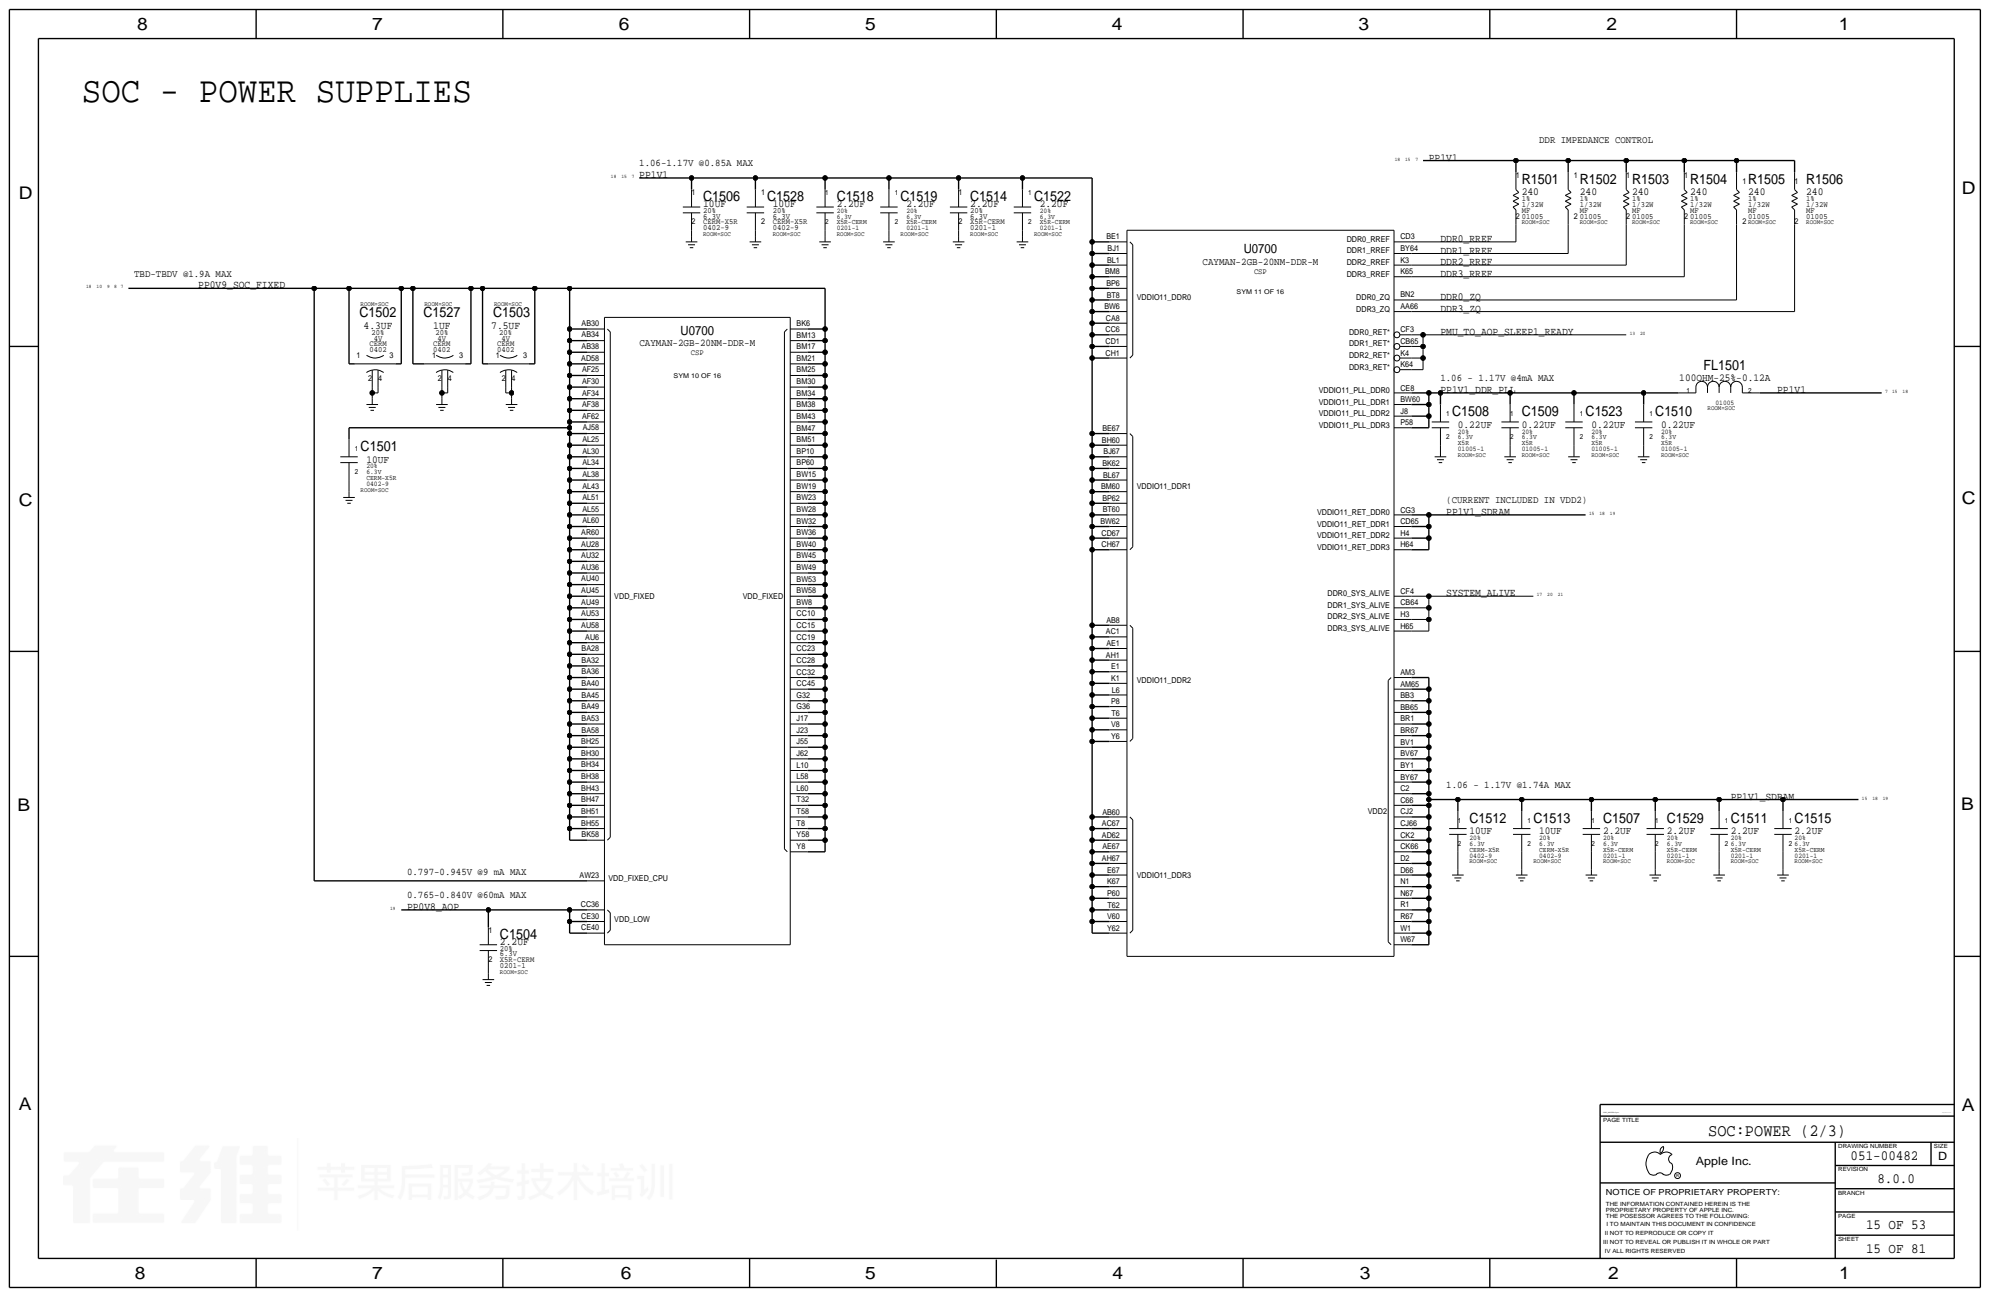
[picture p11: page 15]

# SOC - POWER SUPPLIES

# PROBE POINTS

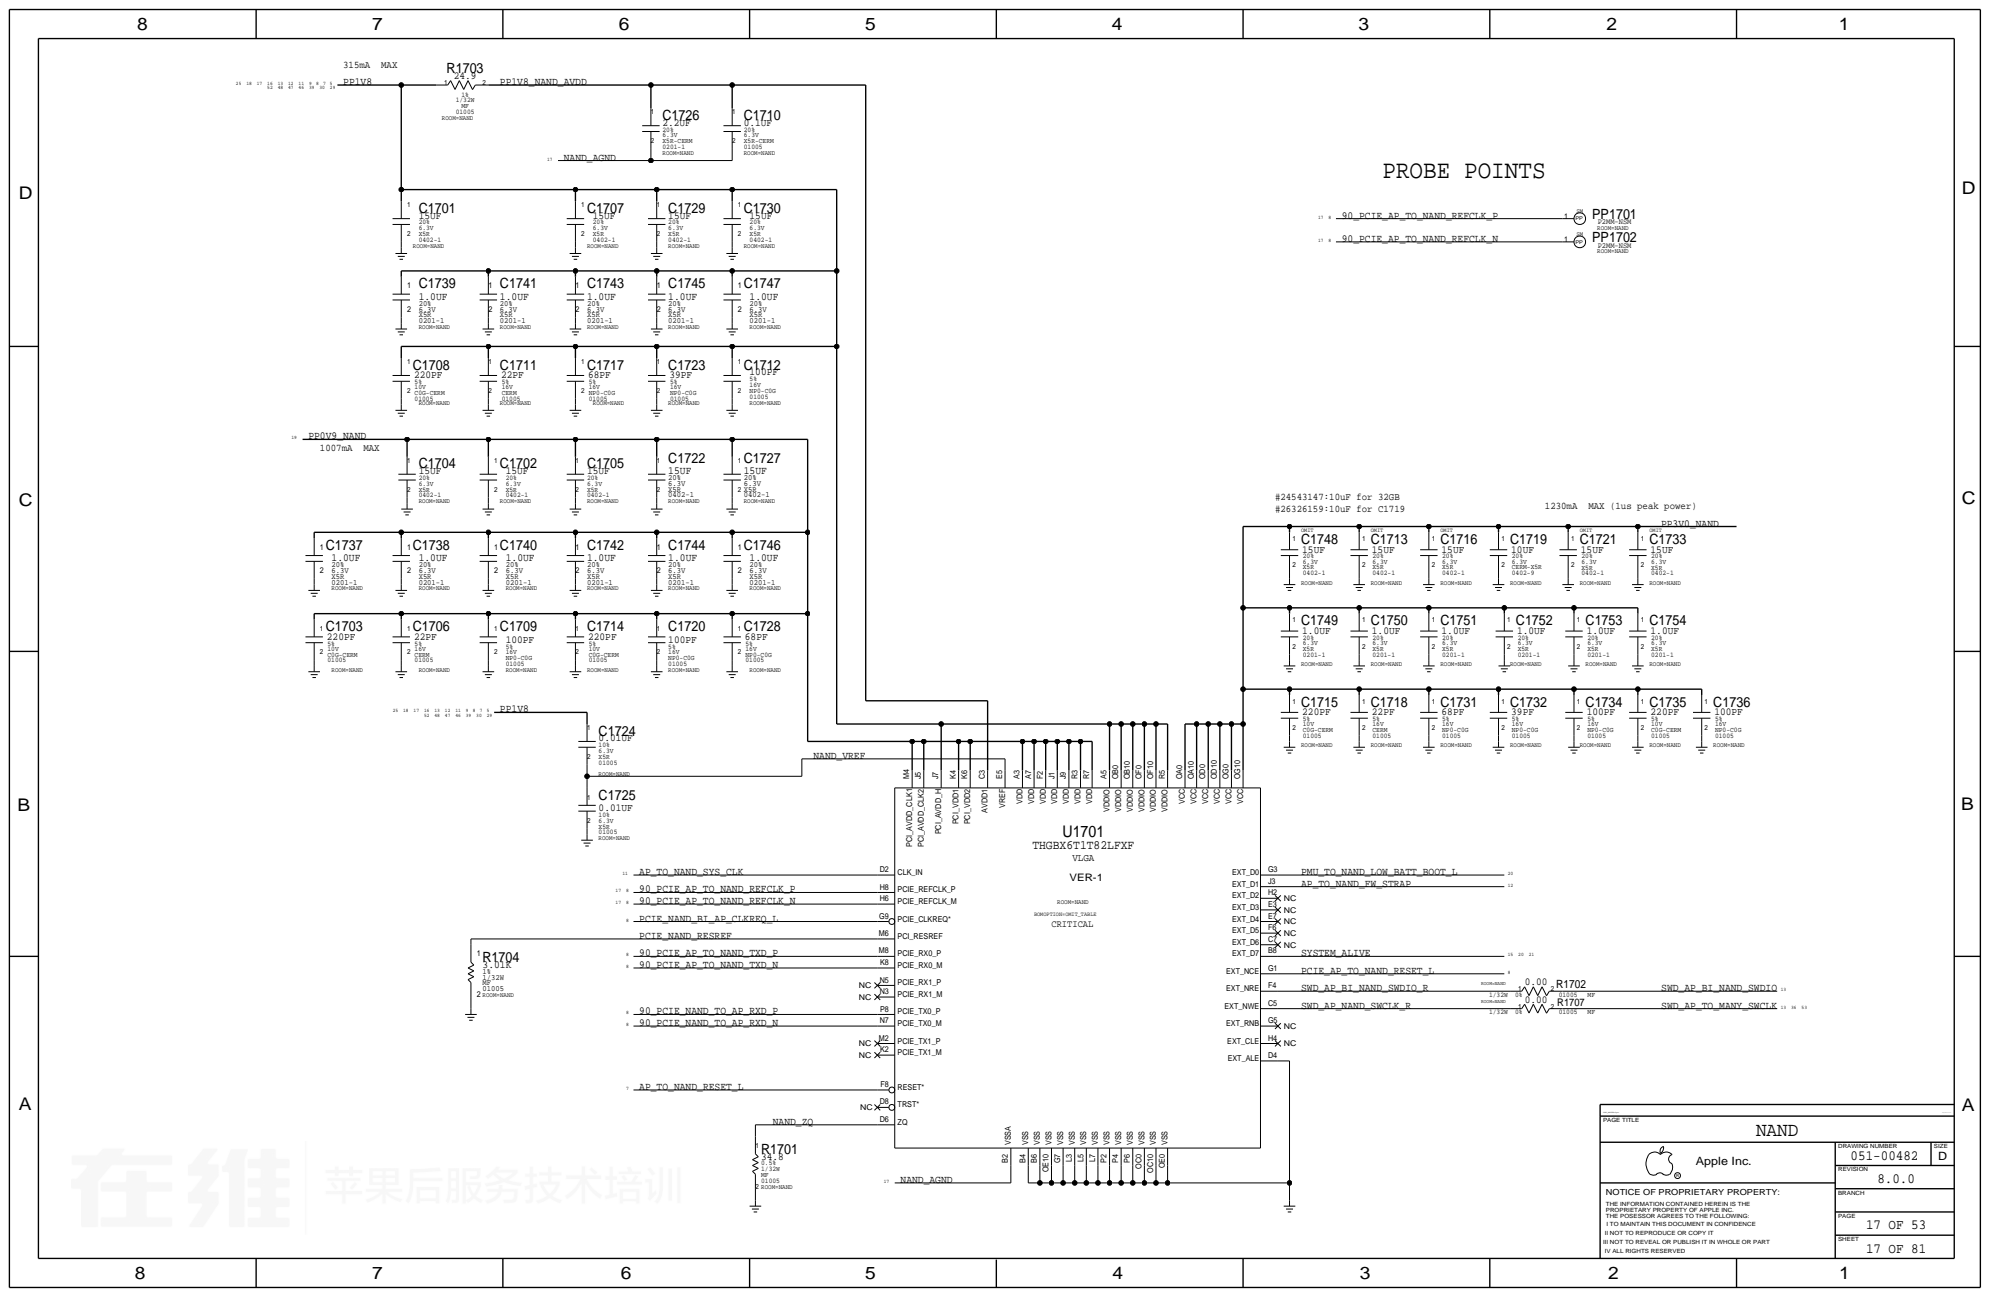
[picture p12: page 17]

R1703 24.9 PP1V8_NAND_AVDD

# SYM 2 OF 4 BAT/USB BUCK INPUT SWITCH OUTPUTS

Voltages per Cayman Power Spec, Sec. 2.2, rev 0.9.2, #24557869

1.5A MAX 0.75A MAX 1.5A MAX BUCK6 1.5A MAX 3.2A MAX BUCK5

# ADELYN LDO SPECS

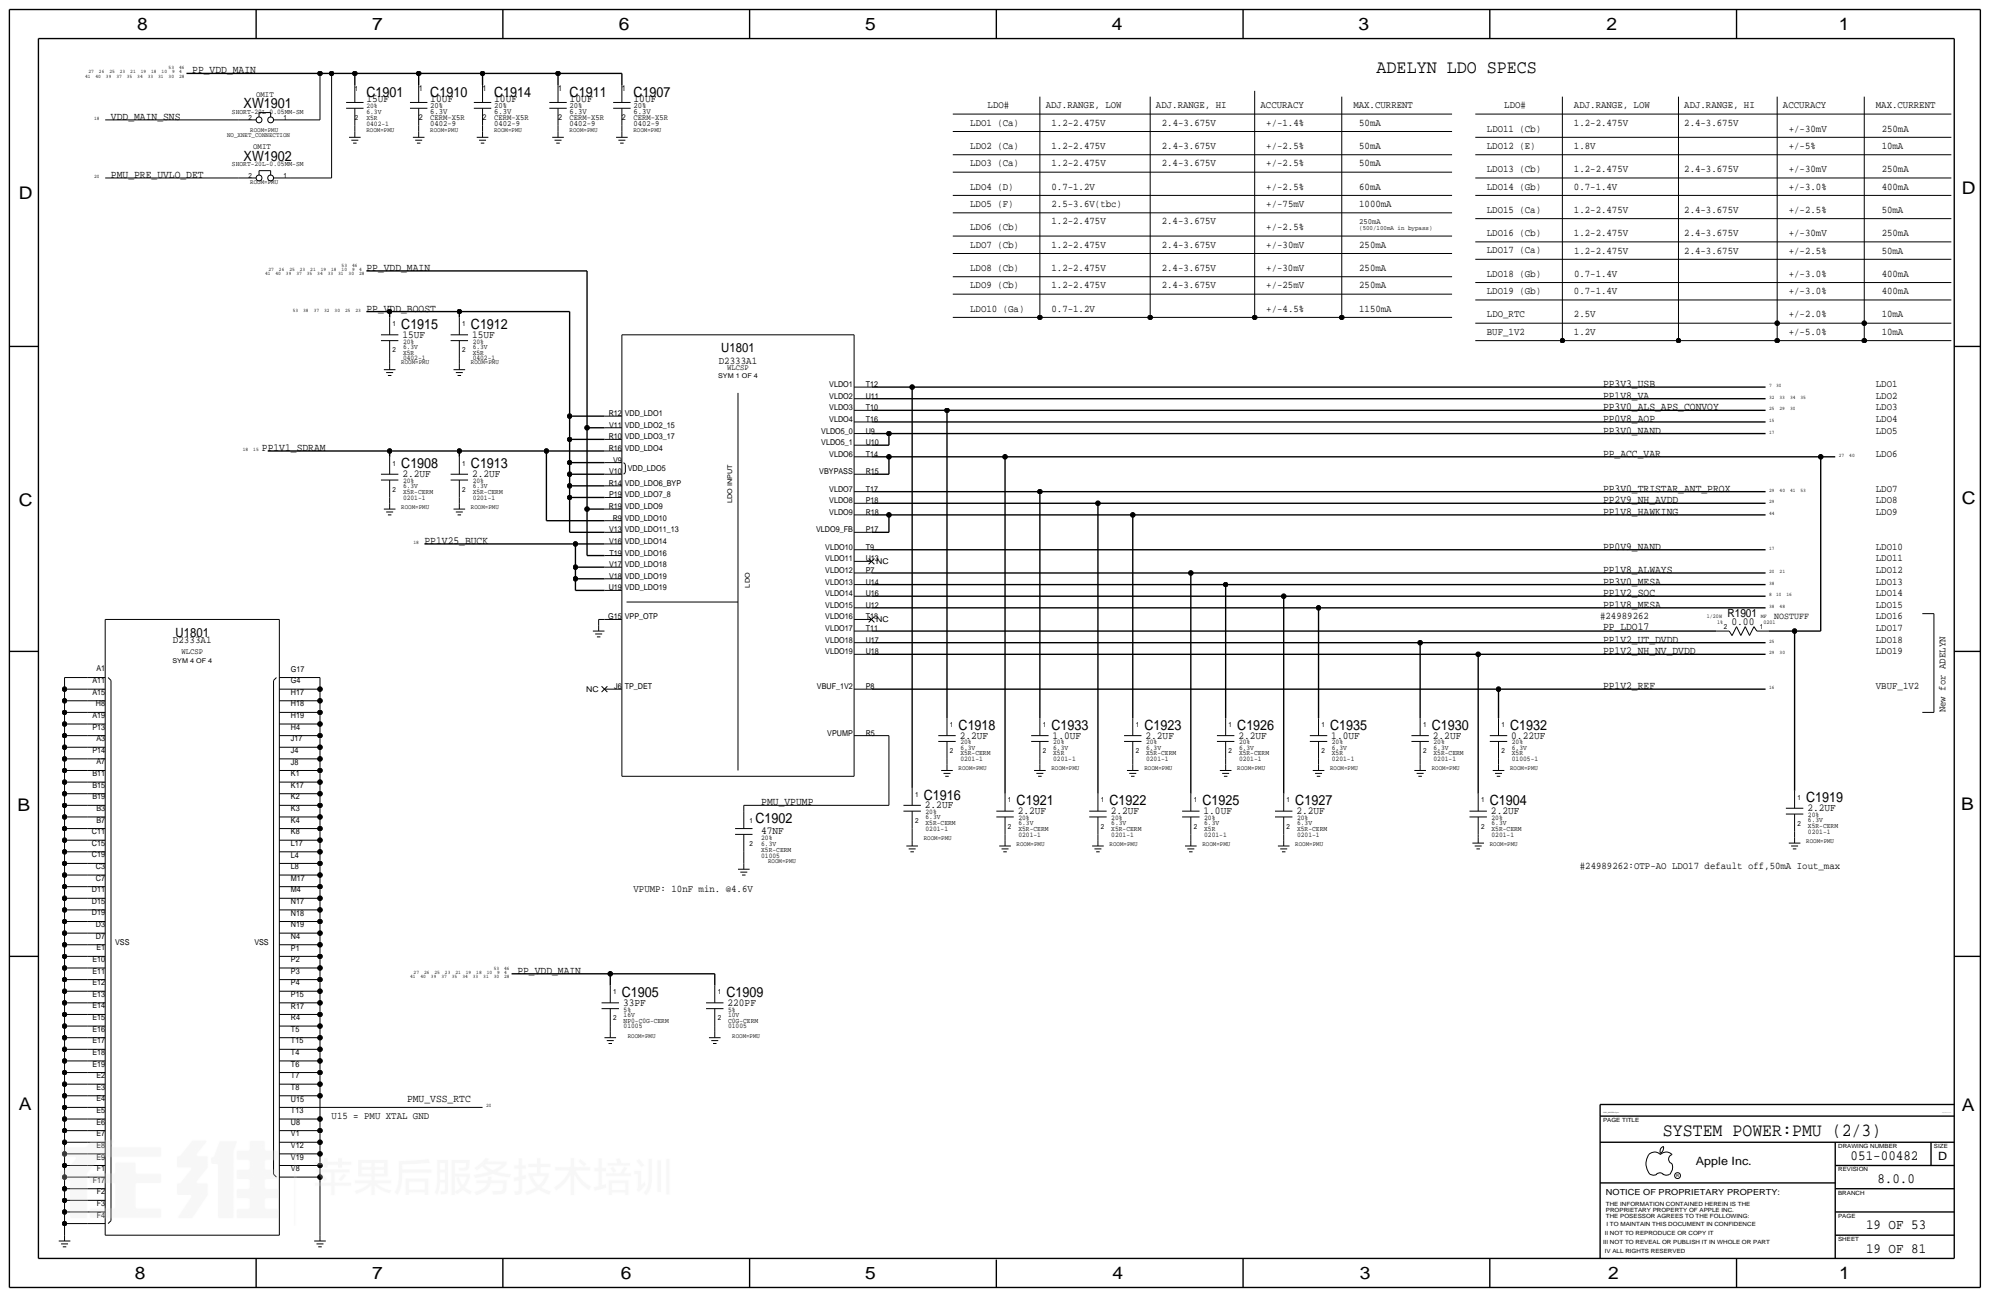
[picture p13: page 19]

P19
R19

#24989262:OTP-AO LDO17 default off,50mA Iout_max

# BUTTON PULL-UP RESISTORS

SYM 3 OF 4 REFS RESETS | COMPARATOR ADC PMGR | BUTTONS AMUX | GPIO NTC XTAL

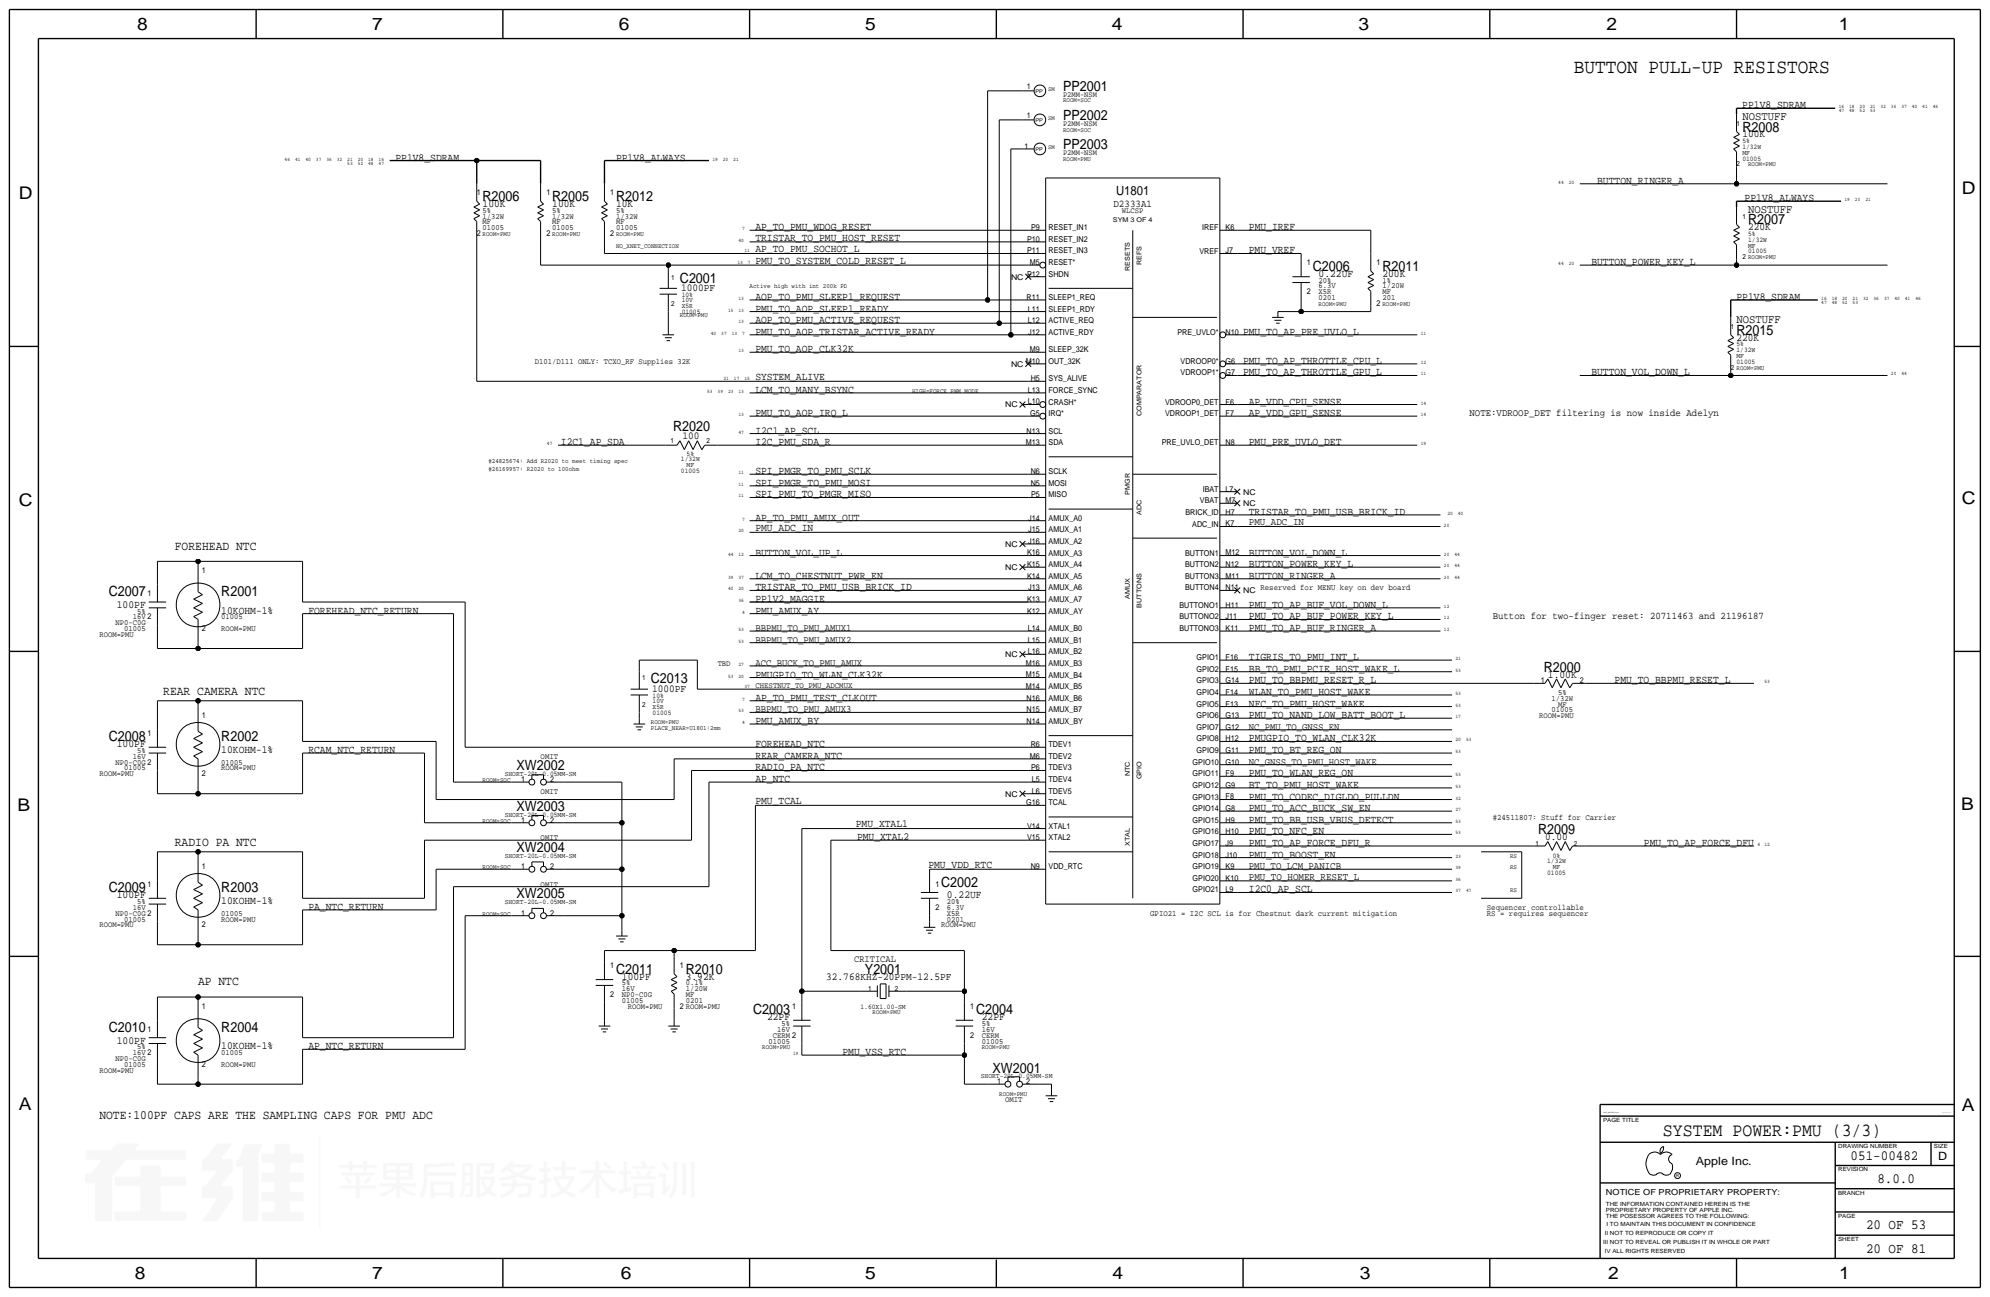
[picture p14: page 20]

Active high with int 200k PD

HIGH=FORCE PWM MODE

NOTE:VDROOP_DET filtering is now inside Adelyn

#24825674: Add R2020 to meet timing spec
#26169957: R2020 to 100ohm

Button for two-finger reset: 20711463 and 21196187

NOTE:100PF CAPS ARE THE SAMPLING CAPS FOR PMU ADC

# TIGRIS CHARGER

F4: 100 kOhm pullup to VLDO (regulated output voltage)
ROOM=CHARGER

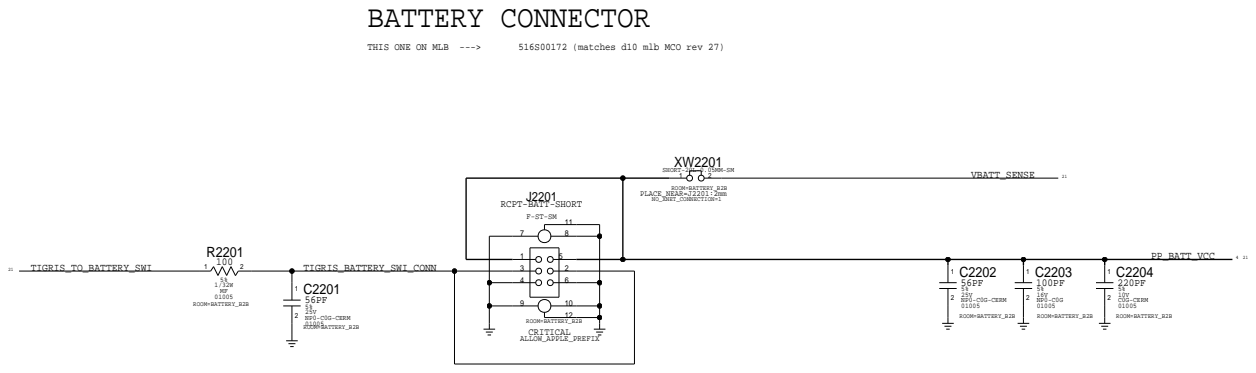
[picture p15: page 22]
BATTERY CONNECTOR; THIS ONE ON MLB --->; 516S00172 (matches d10 mlb MCO rev 27); VBATT_SENSE; TIGRIS_TO_BATTERY_SWI; PP_BATT_VCC; TIGRIS_BATTERY_SWI_CONN; SYNC_MASTER=Sync; SYNC_DATE=06/06/2016; ROOM=BATTERY_B2B; NP0-C0G-CERM; C0G-CERM; SHORT-20L-0.05MM-SM; ROOM=BATTERY_B2B NO_XNET_CONNECTION=1; PLACE_NEAR=J2201:2mm; ROOM=BATTERY_B2B CRITICAL ALLOW_APPLE_PREFIX; REVISION; DRAWING NUMBER; SIZE; Apple Inc.

RCPT-BATT-SHORT

PAGE TITLE
SYSTEM POWER:BATTERY CONN

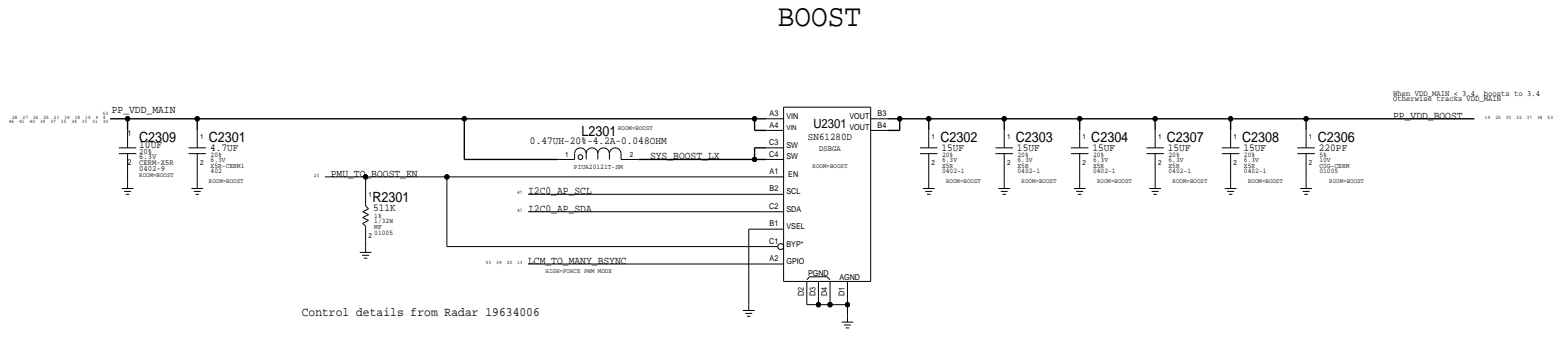
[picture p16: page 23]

LCM_TO_MANY_BSYNC
HIGH=FORCE PWM MODE

Control details from Radar 19634006

# MAGNESIUM - COMPASS CARBON - ACCEL & GYRO

#25740540:PP for South Carbon MOSI

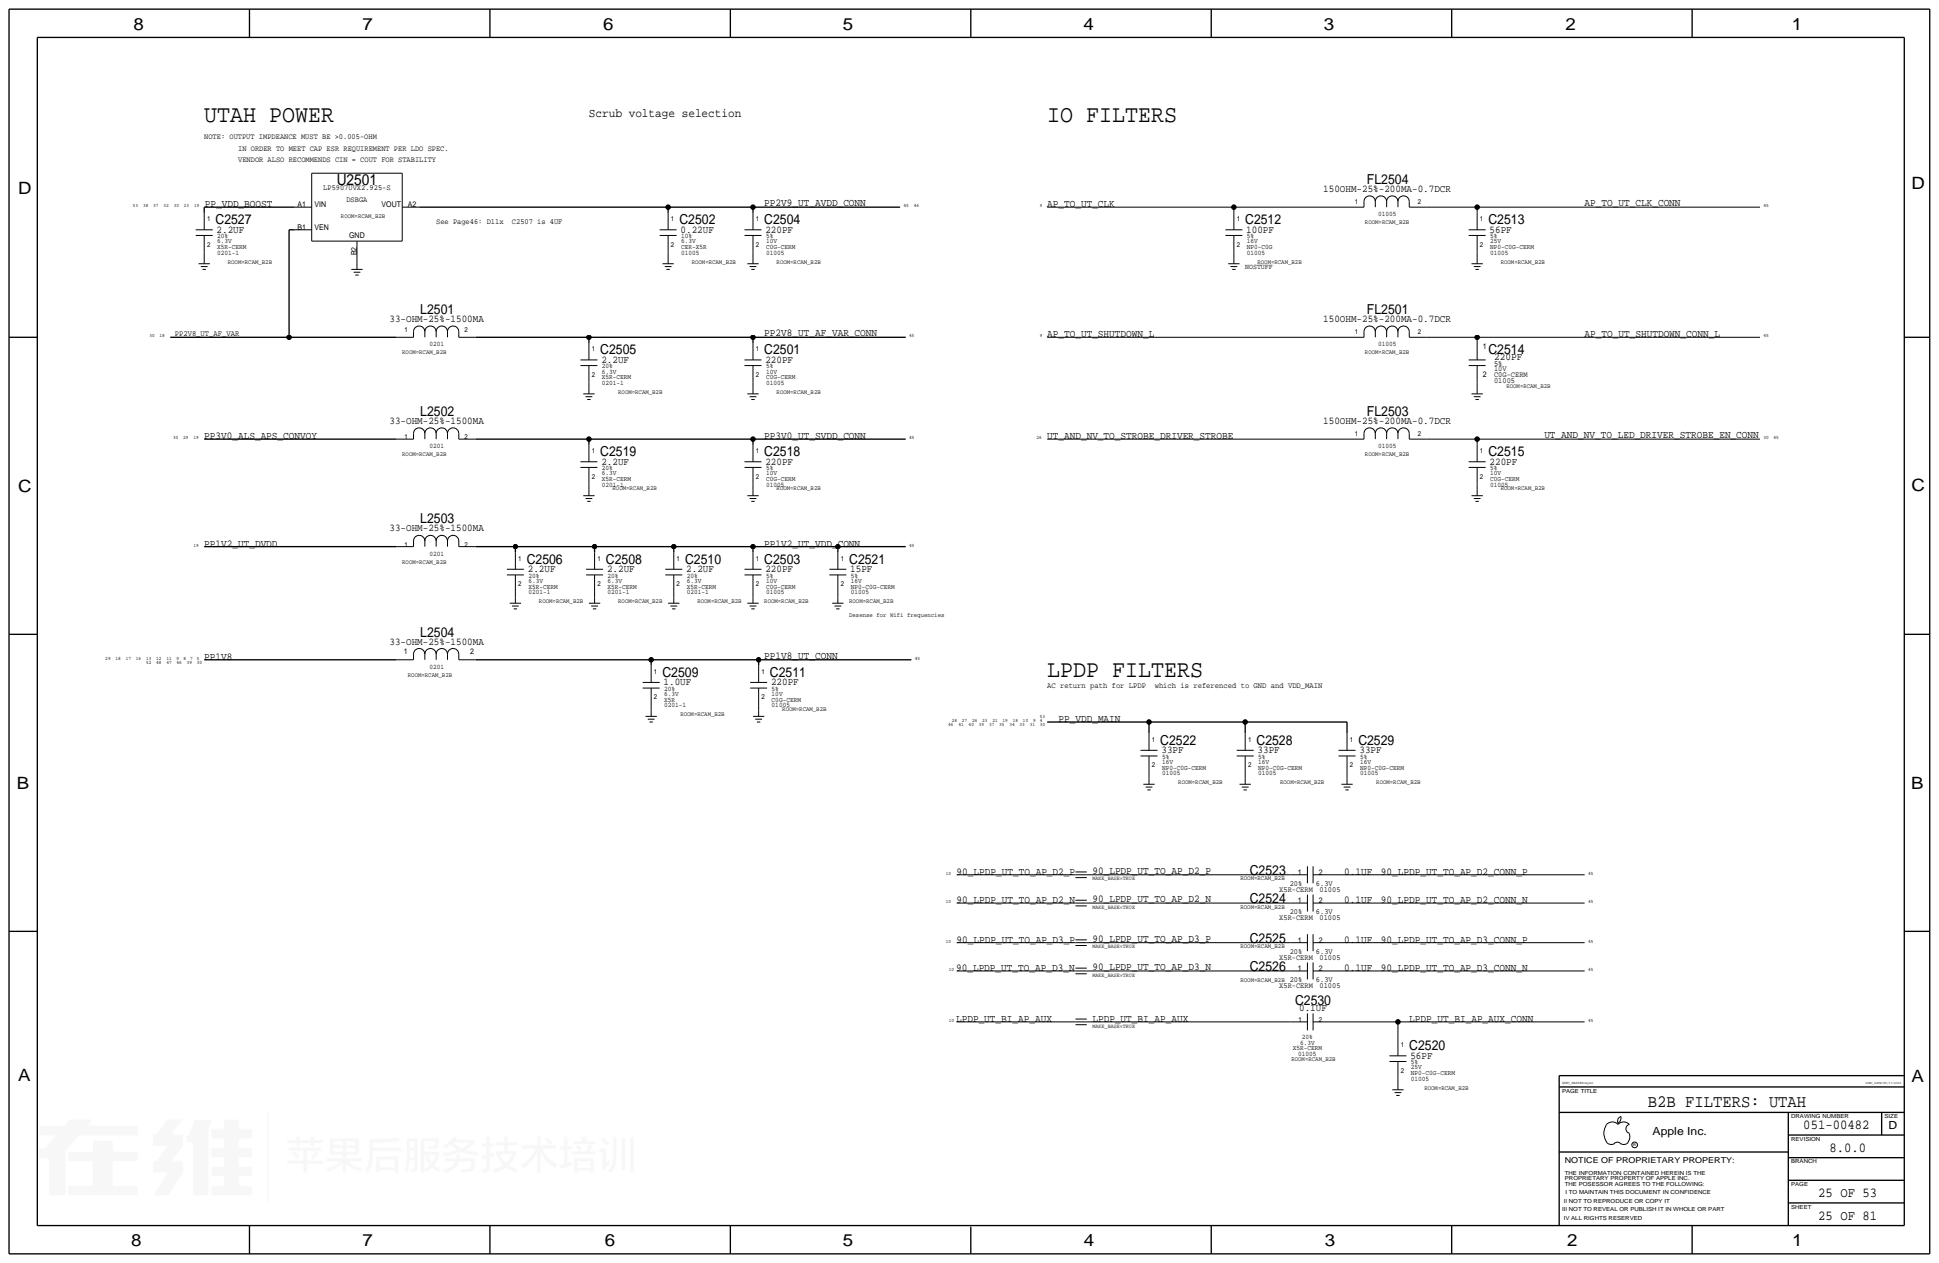
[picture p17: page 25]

NOTE: OUTPUT IMPDEANCE MUST BE >0.005-OHM
IN ORDER TO MEET CAP ESR REQUIREMENT PER LDO SPEC.
VENDOR ALSO RECOMMENDS CIN = COUT FOR STABILITY

AC return path for LPDP which is referenced to GND and VDD_MAIN
PP_VDD_MAIN

## D10/sip_neo

# STROBE DRIVERS INSIDE NEO SIP MODULE

A5 | C17
A6 | C18
A7 | C19
A8 | C20
A9 | D1
A10 | D4
A11 | D5
A12 | D14
A13 | D15
A14 | D16
A15 | D17
A16 | D18
A17 | D19
A18 | E1
A19 | E2
A20 | E3
B2 | E4
B3 | E5
B4 | E6
B5 | E7
B6 | E8
B7 | E9
B16 | E10
B17 | E11
B20 | E12
C1 | E13
C2 | E14
C3 | E15
C4 | E16
C5 | E17
C6 | E18
C7 | E19

# ACCESSORY BUCK

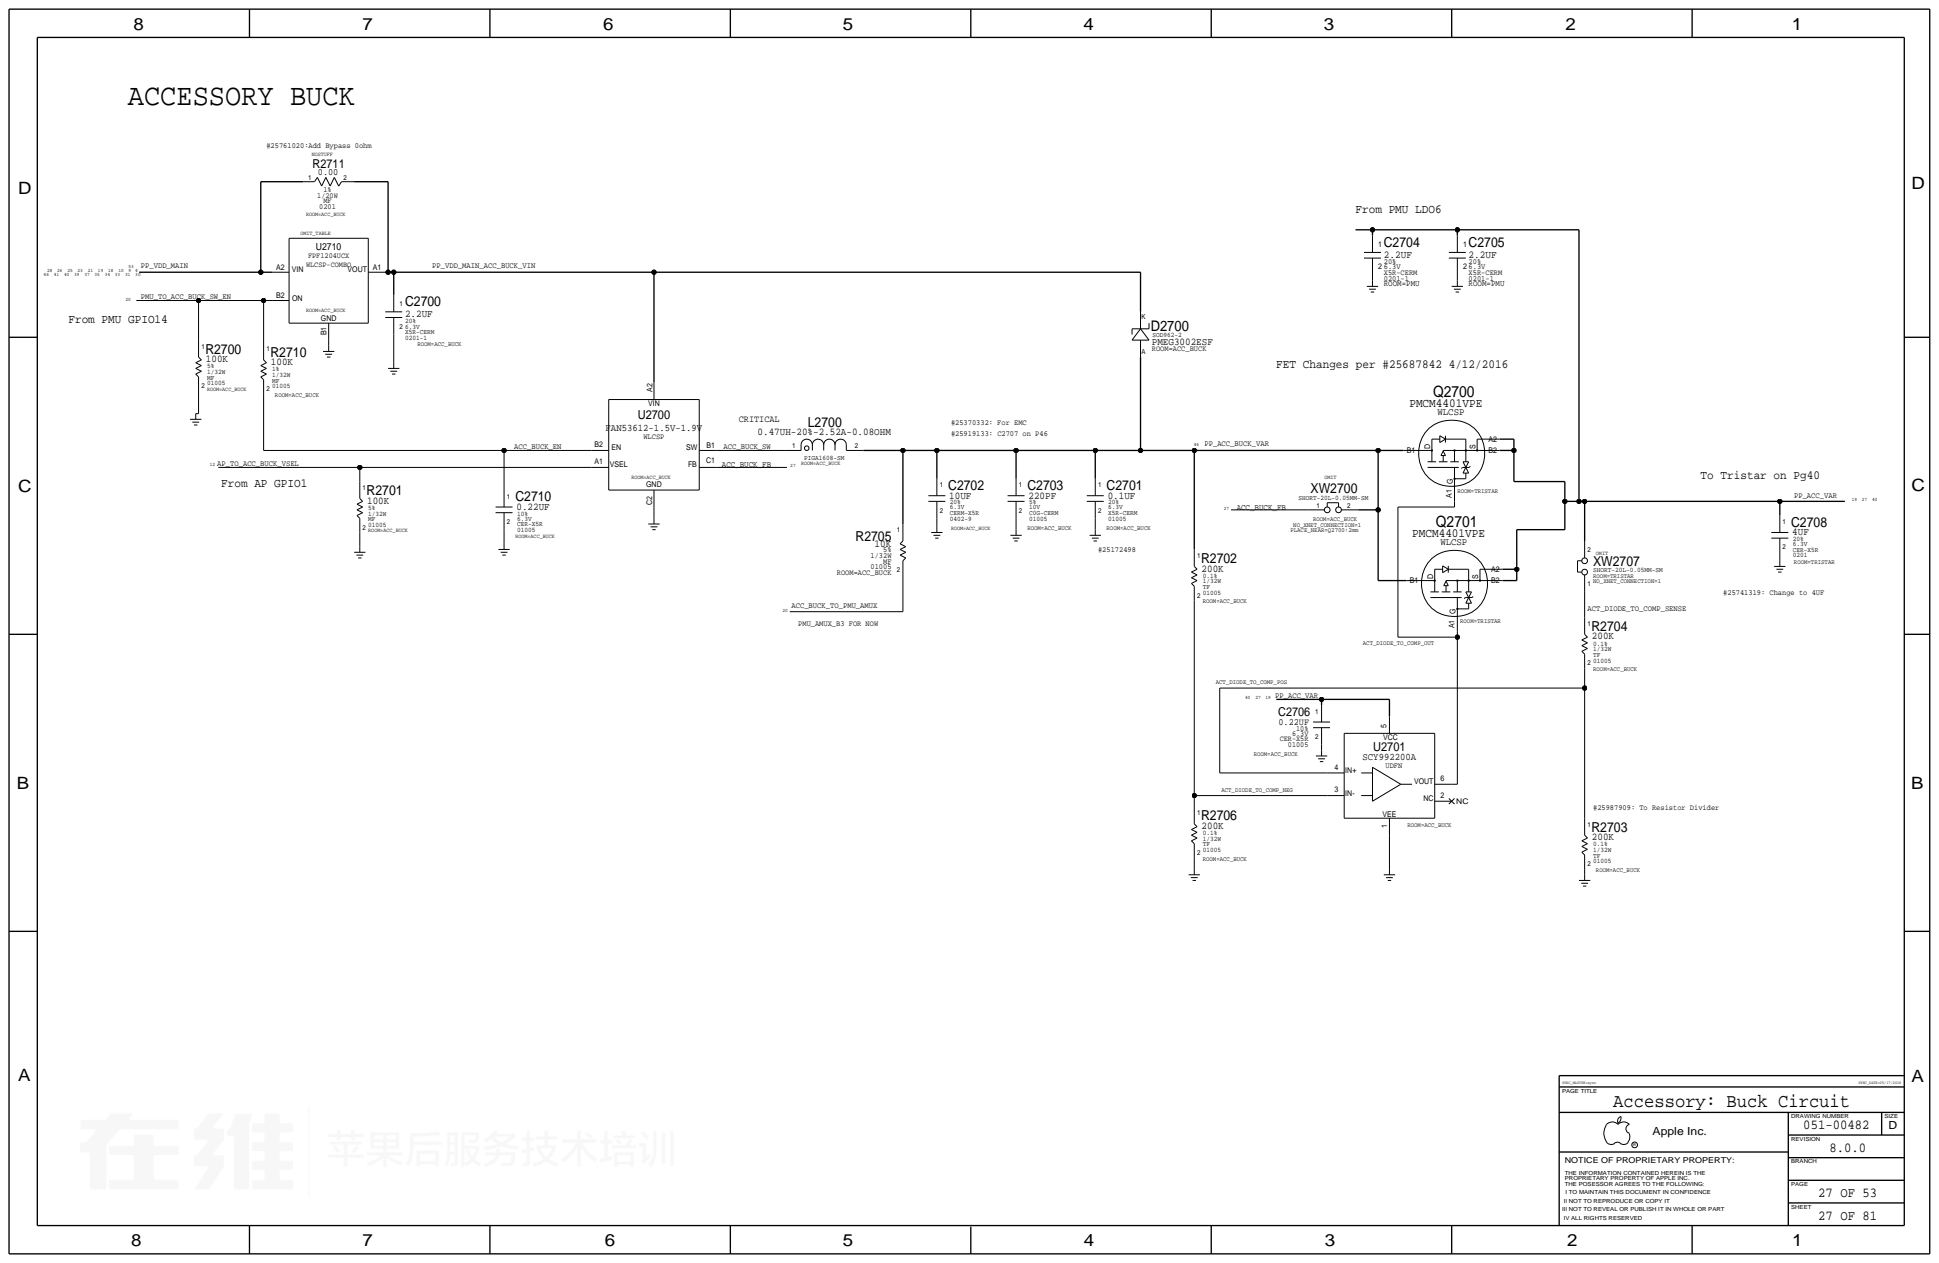
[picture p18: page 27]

A4 | M7
A5 | N1
A6 | N2
A7 | N3
B1 | N5
B4 | N7

C1 | P2
C2 | P3
C3 | P4
C4 | P5
C5 | P6
C6 | P7
C7 | Q1

D4 | Q4
D7 | Q5
E1 | Q7
E2 | R1
E3 | R3
E4 | R4

F1 | S3
F3 | S4
F4 | S5
F5 | S7

G1 | T3
G3 | T4
G4 | T5
G5 | T7
G7 | U1
H1 | U2

H7 | U6
J1 | U7
J3 | V1
J4 | V4
J5 | V7
J7 | W1
K1 | W2

K3 | W4
K4 | W5
K5 | W6
K6 | W7
K7 | X1
L1 | X4
L2 | X7
L3 | Y1
L5 | Y2
L7 | Y3
M1 | Y4
M2 | Y5

# PROX, ALS, & CONVOY POWER

# NEW HAMPSHIRE POWER

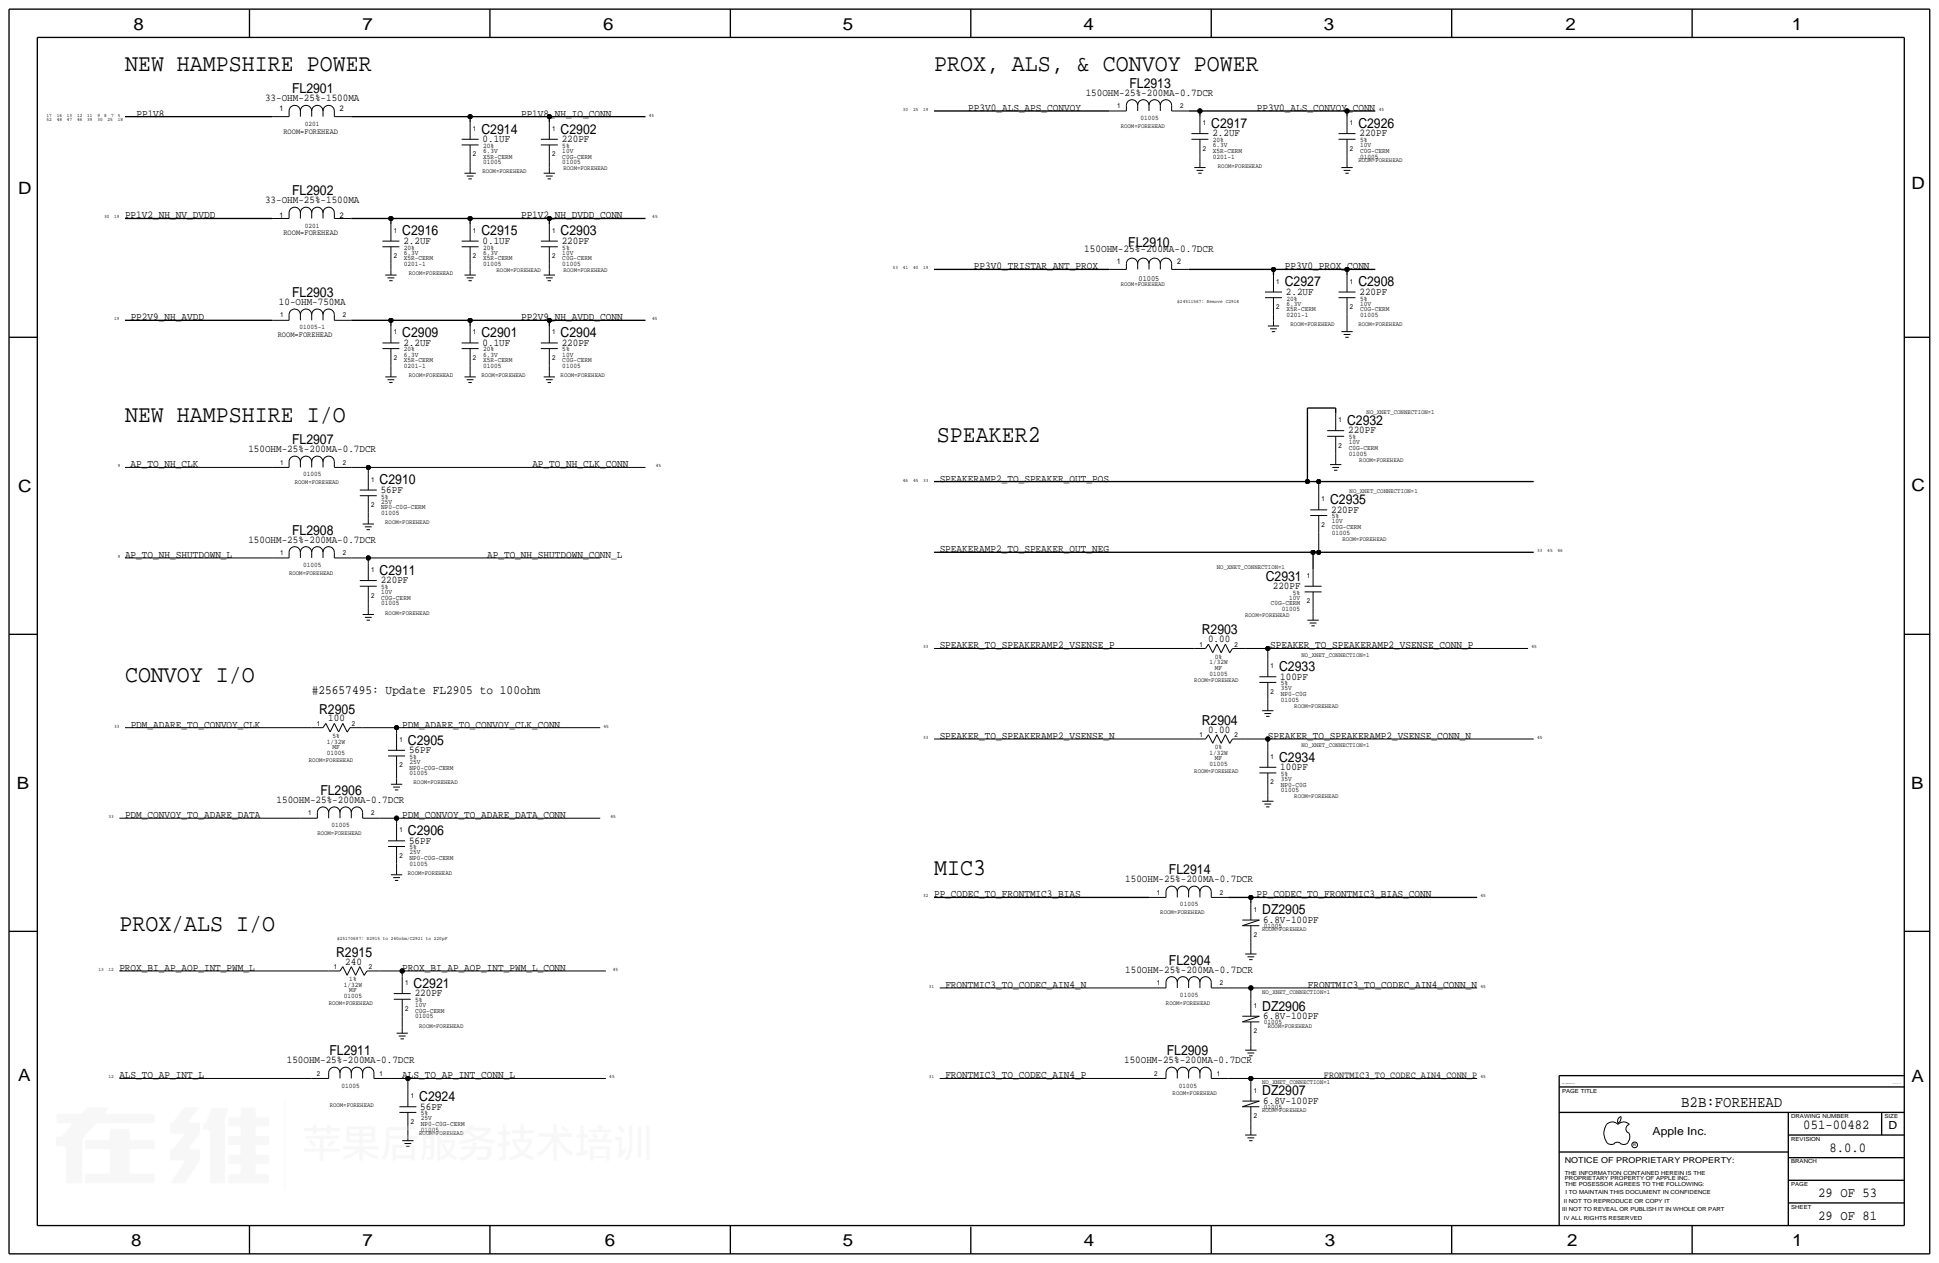
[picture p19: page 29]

# THIS PAGE UNIQUE TO LARGE FORM FACTOR

# NEVADA CONNECTOR

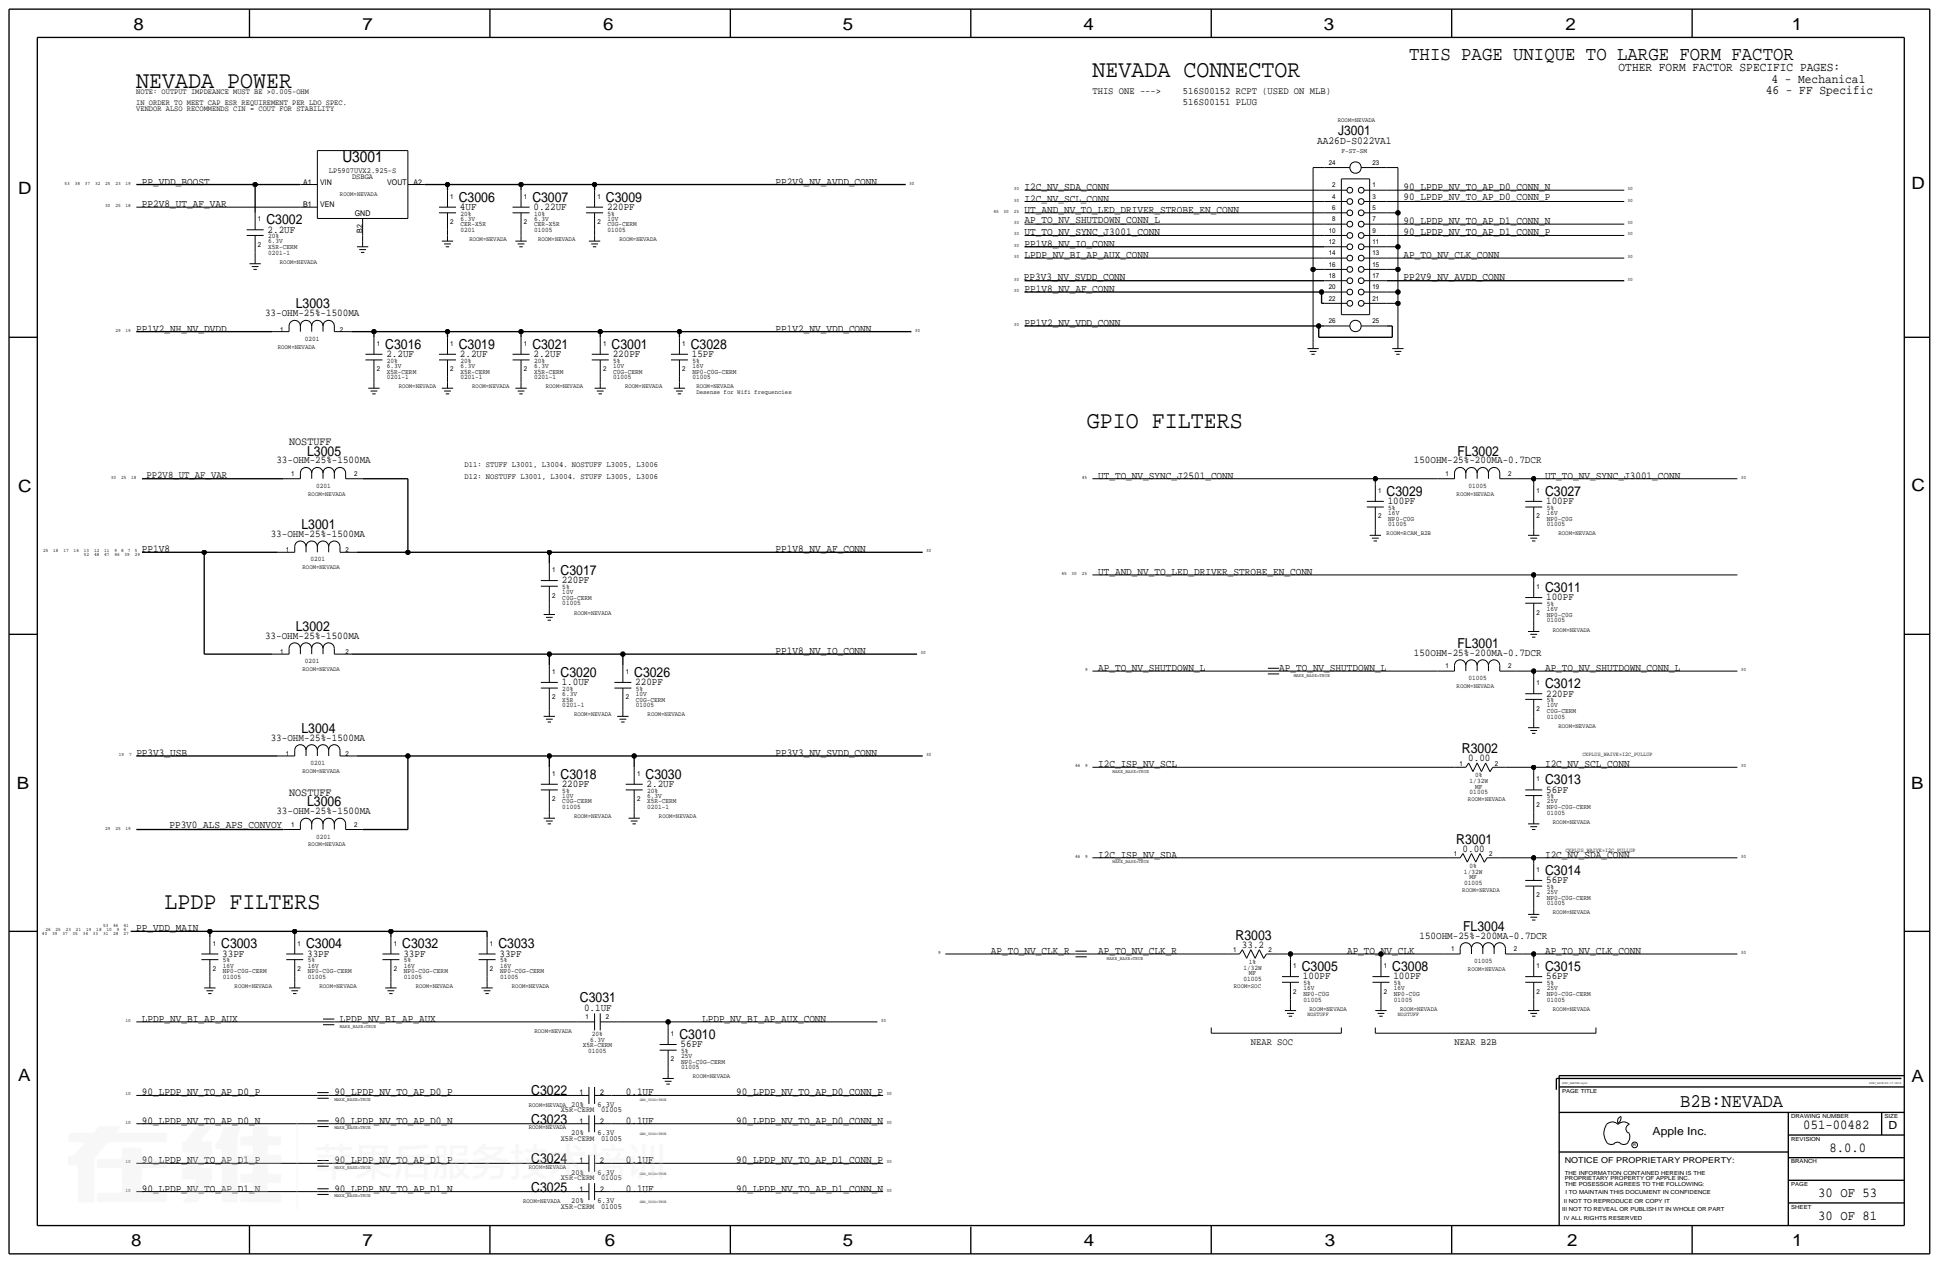
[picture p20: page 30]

OTHER FORM FACTOR SPECIFIC PAGES:

NEVADA POWER
NOTE: OUTPUT IMPDEANCE MUST BE >0.005-OHM
IN ORDER TO MEET CAP ESR REQUIREMENT PER LDO SPEC.
VENDOR ALSO RECOMMENDS CIN = COUT FOR STABILITY

516S00152 RCPT (USED ON MLB)
516S00151 PLUG

# CALTRA AUDIO CODEC (ANALOG INPUTS & OUTPUTS)

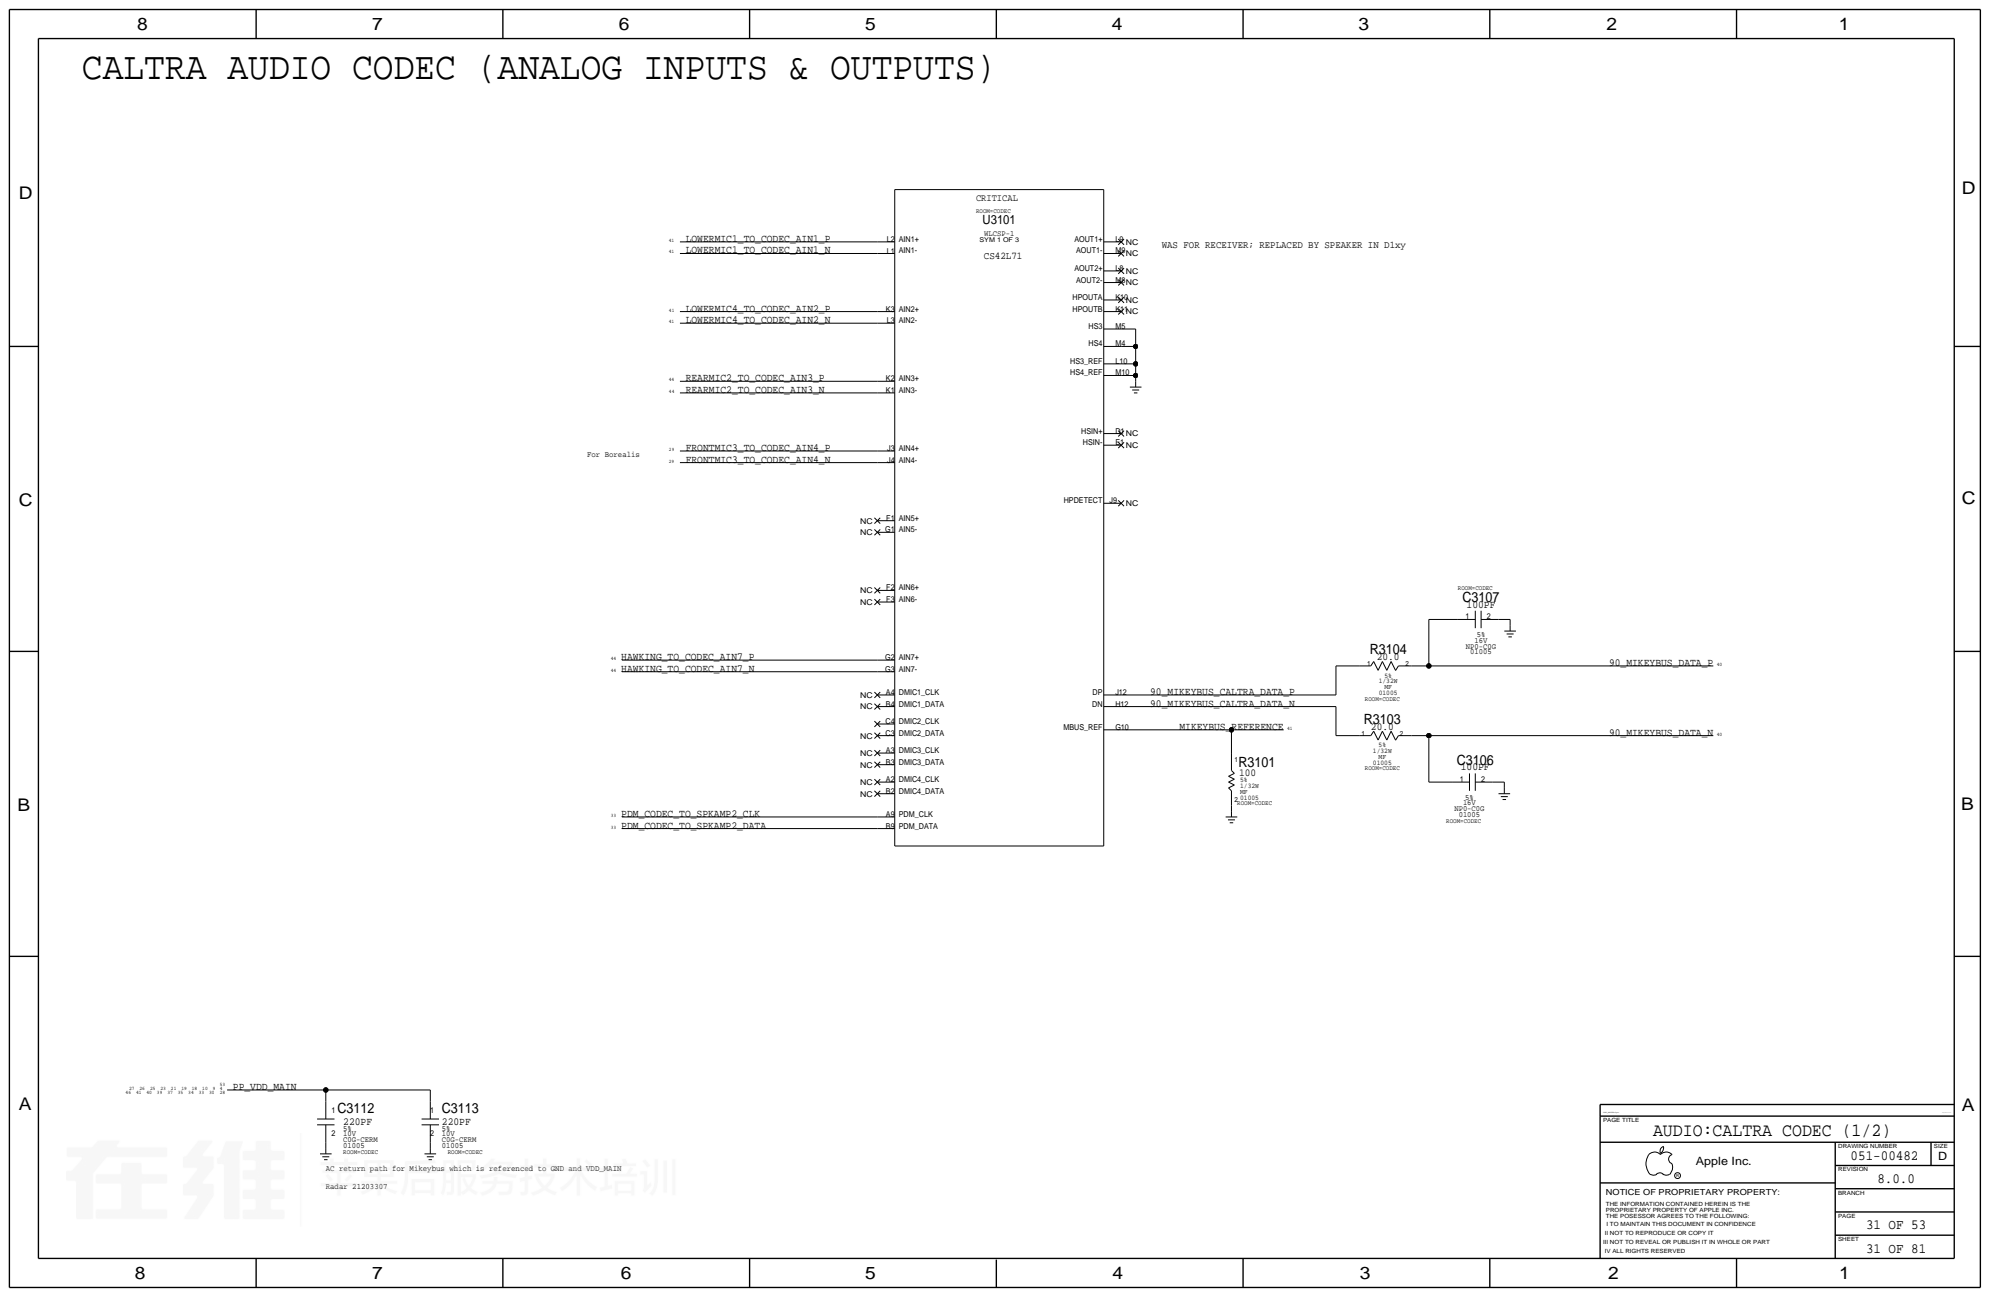
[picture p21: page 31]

WAS FOR RECEIVER; REPLACED BY SPEAKER IN D1xy

# CALTRA AUDIO CODEC (POWER & I/O)

# SPEAKER AMPLIFIER 2 (North)

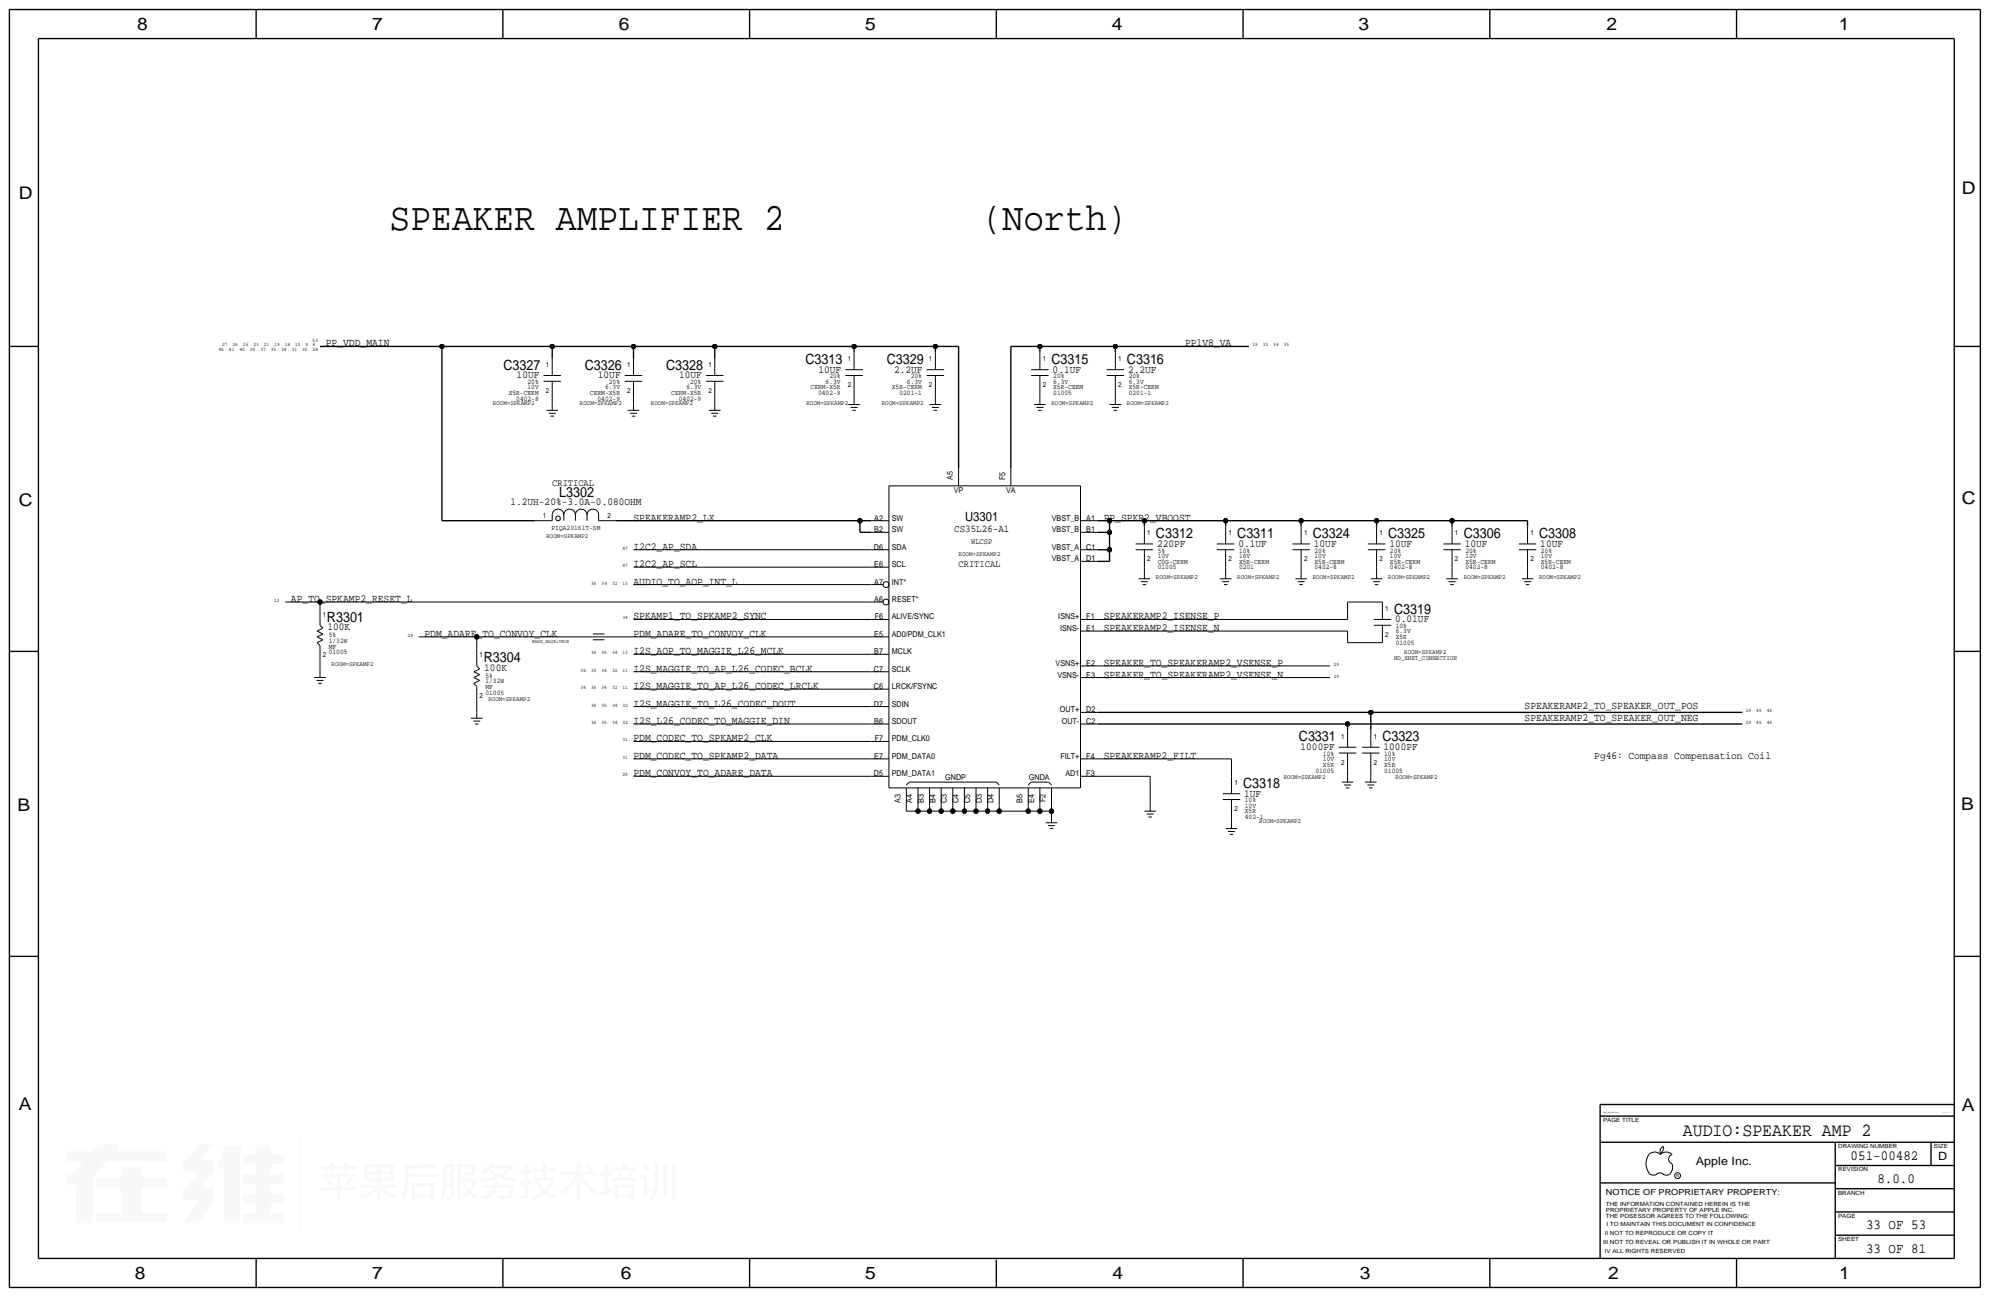
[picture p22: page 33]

# (South) SPEAKER AMPLIFIER 1

PULLED LOW ON PG 35
AOP_TO_SPKAMP1_ARC_RESET_L

# ARC DRIVER

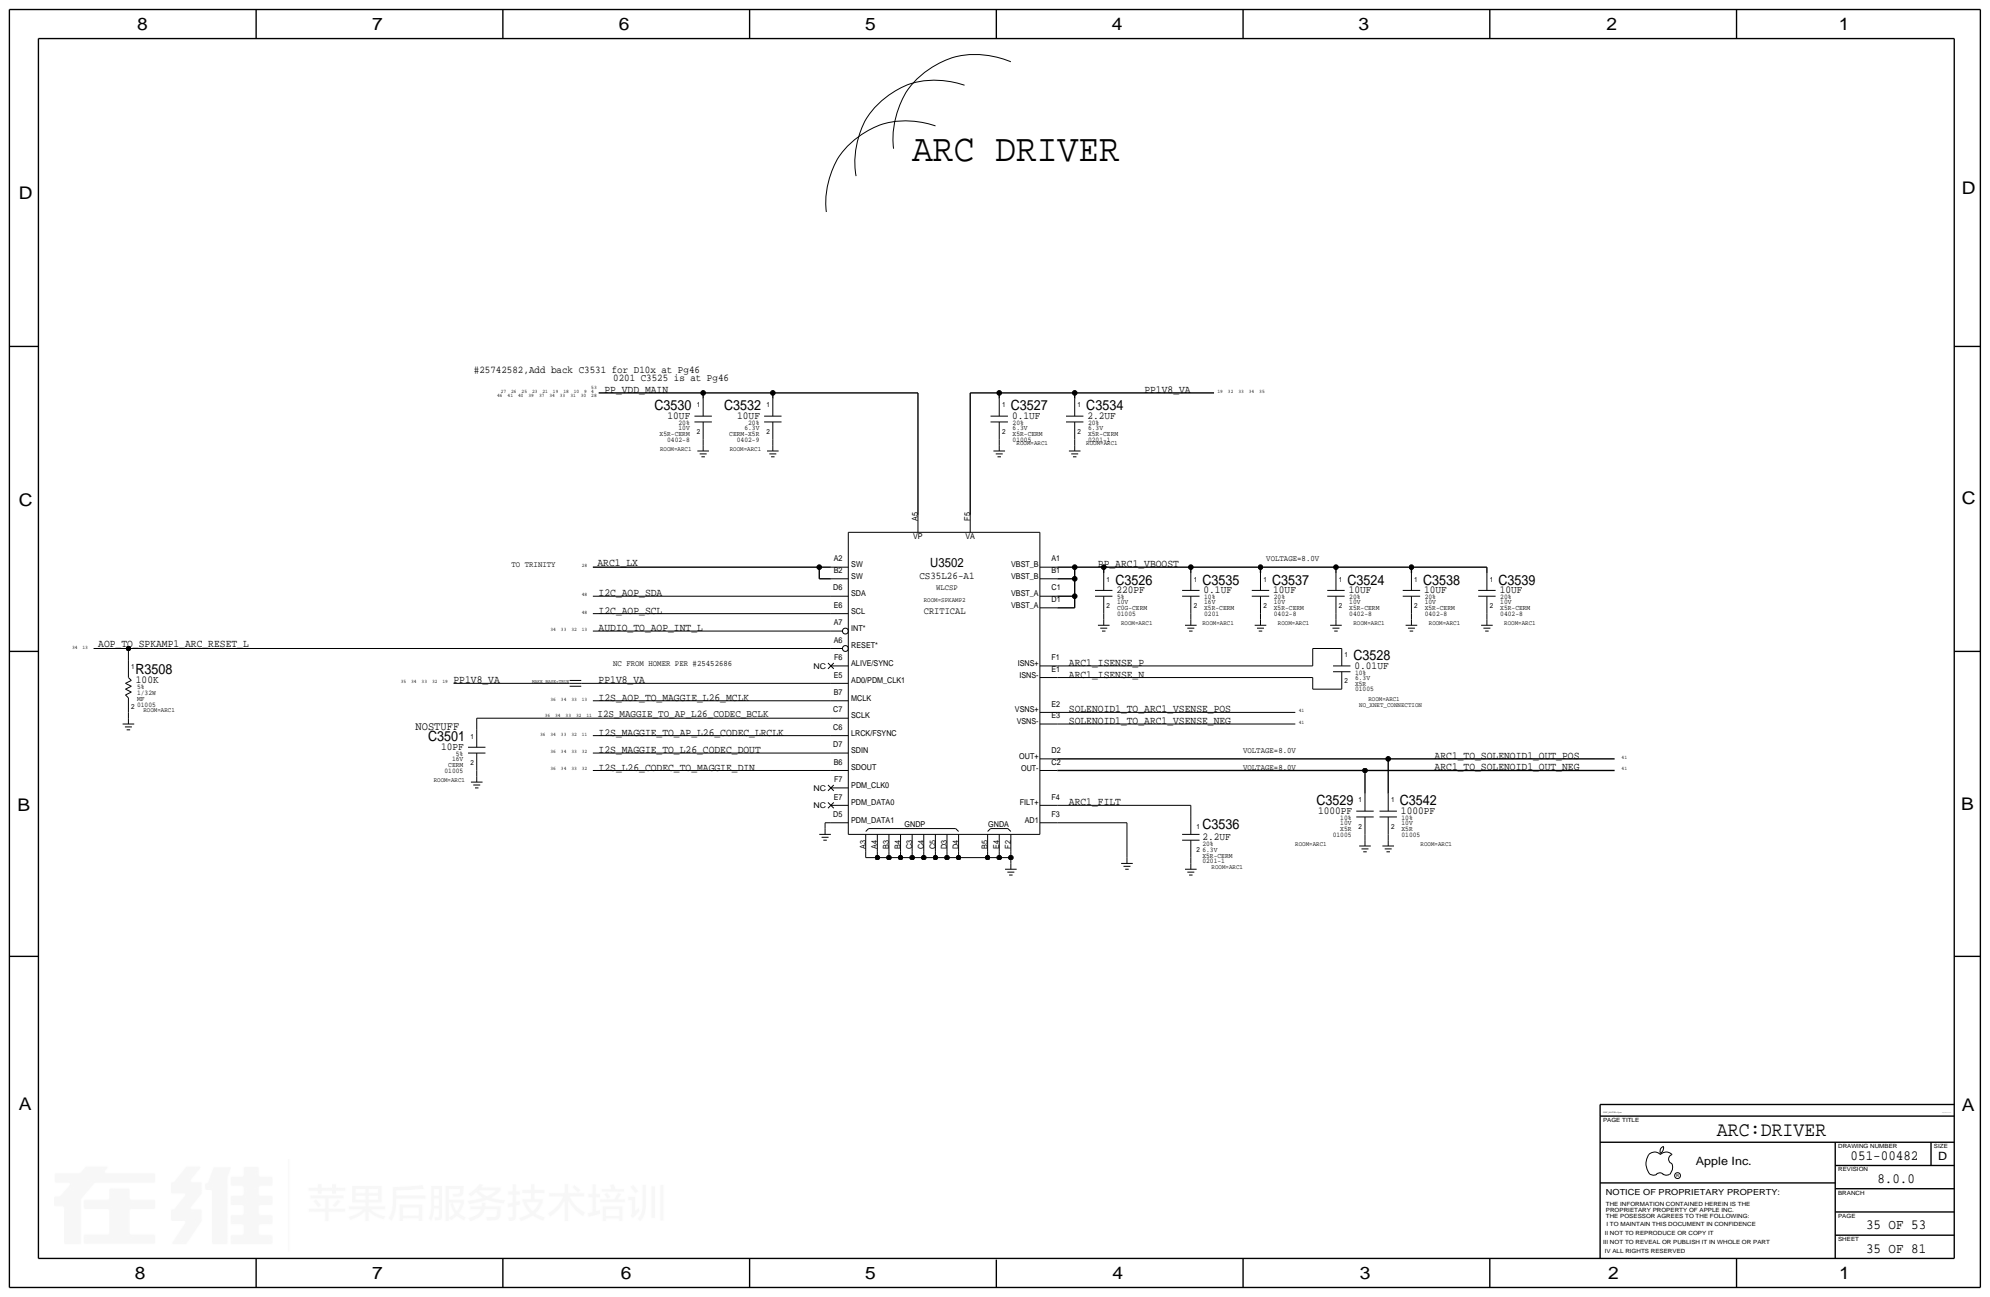
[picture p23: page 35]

#25742582,Add back C3531 for D10x at Pg46

MAGGIE LDO | MAGGIE

VPP_2V5 must be > 1.71V for SPI Slave programming
PP1V8_MAGGIE_IMU

MAGGIE DRIVES TO ARC, SPKRS, AP, CODEC

MAGGIE <-> ARC, SPKRS, CODEC (SDOUT)
MAGGIE <-> ARC, SPKRS, CODEC (SDIN)
MAGGIE <-> AP (SDOUT)

# CHESTNUT DISPLAY PMU

# DISPLAY & TOUCH - POWER SUPPLIES

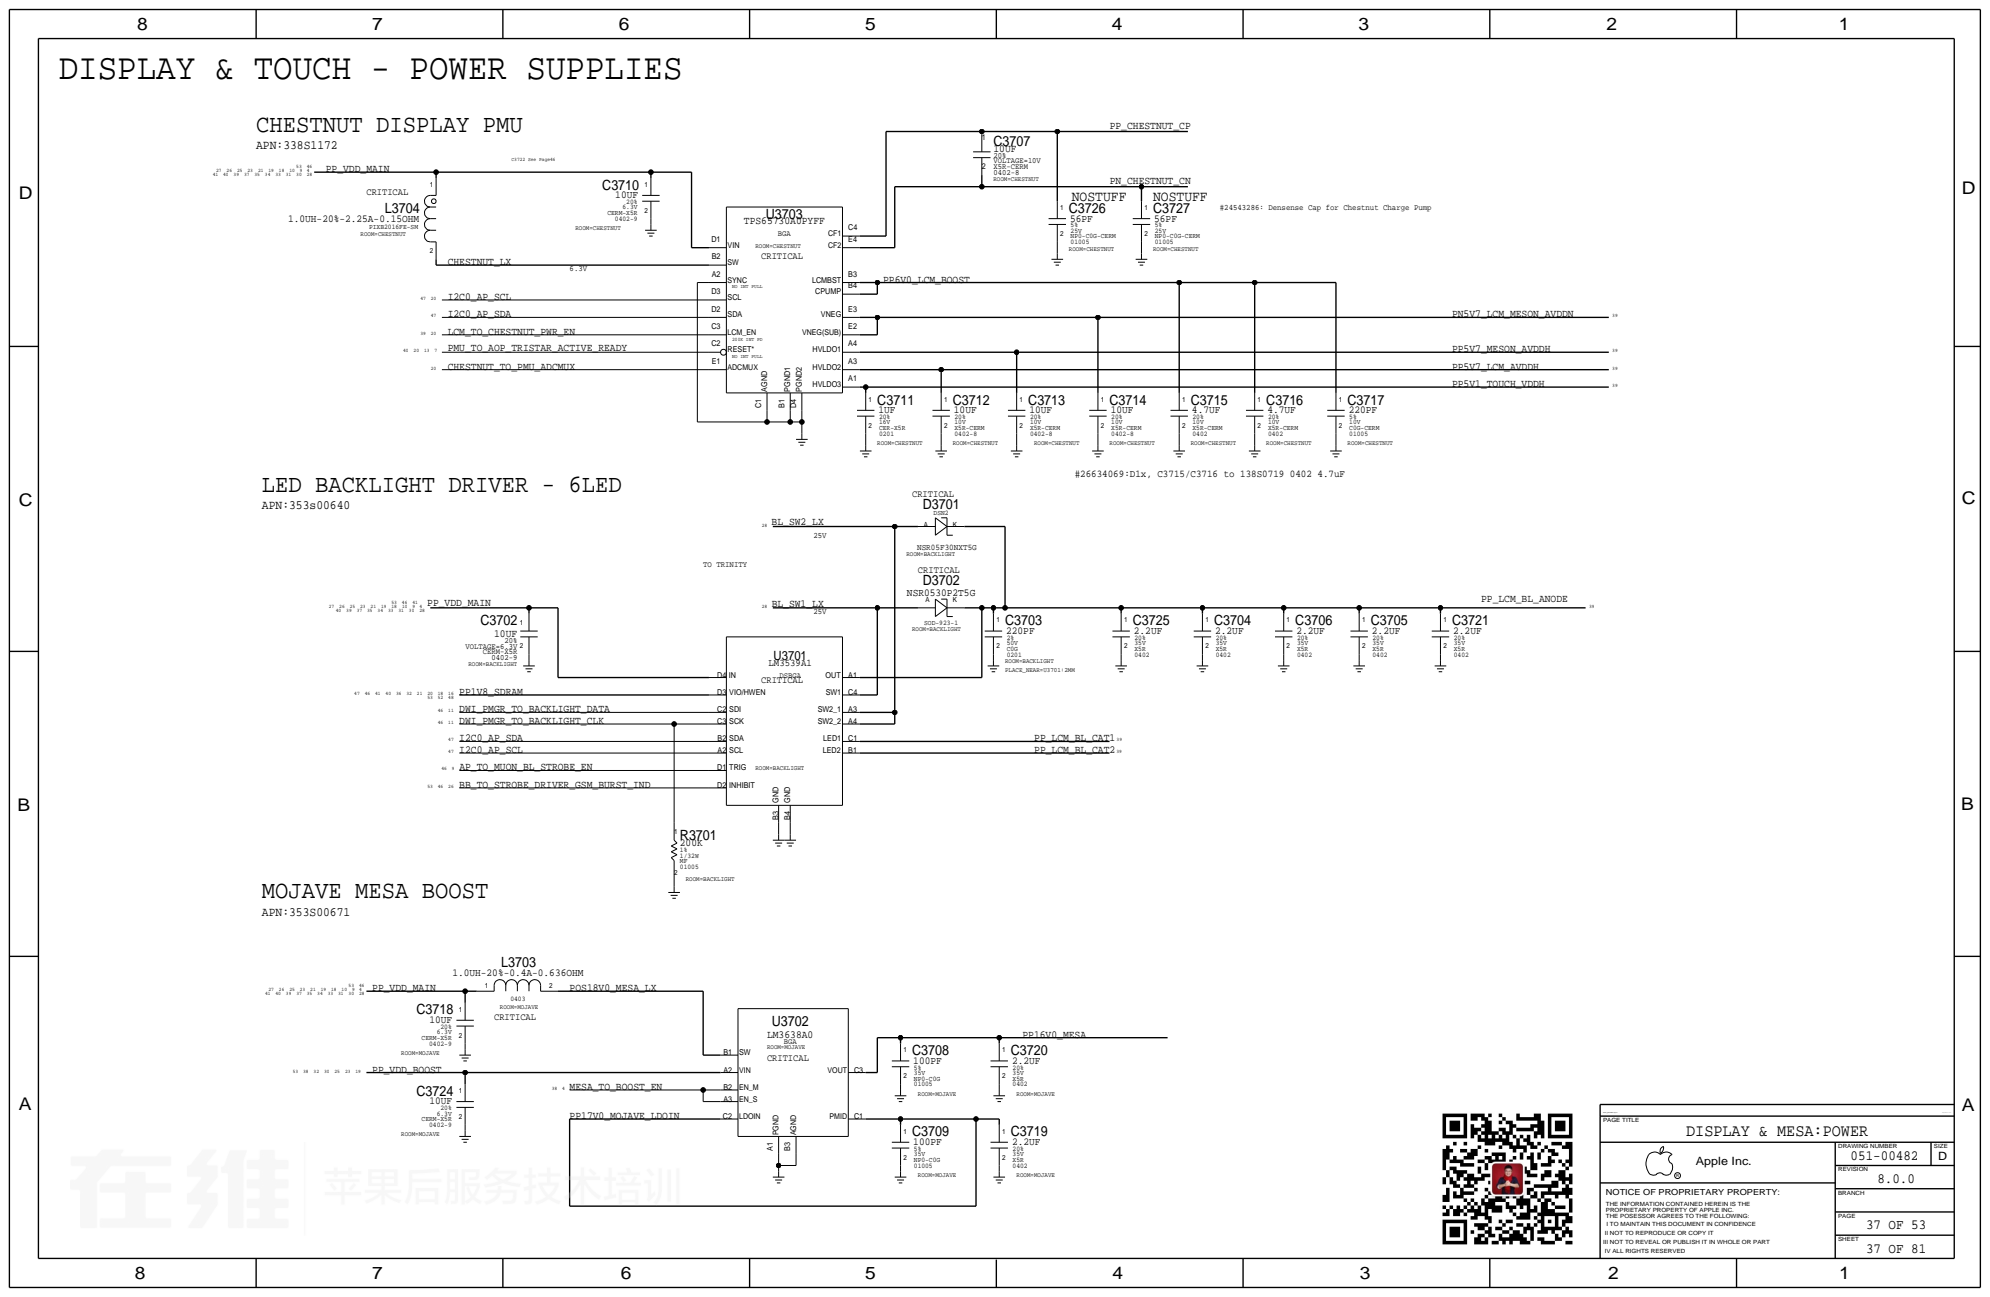
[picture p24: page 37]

PP_CHESTNUT_CP

#24543286: Densense Cap for Chestnut Charge Pump

# MAMBA AND MESA CONNECTOR

# MESA POWER

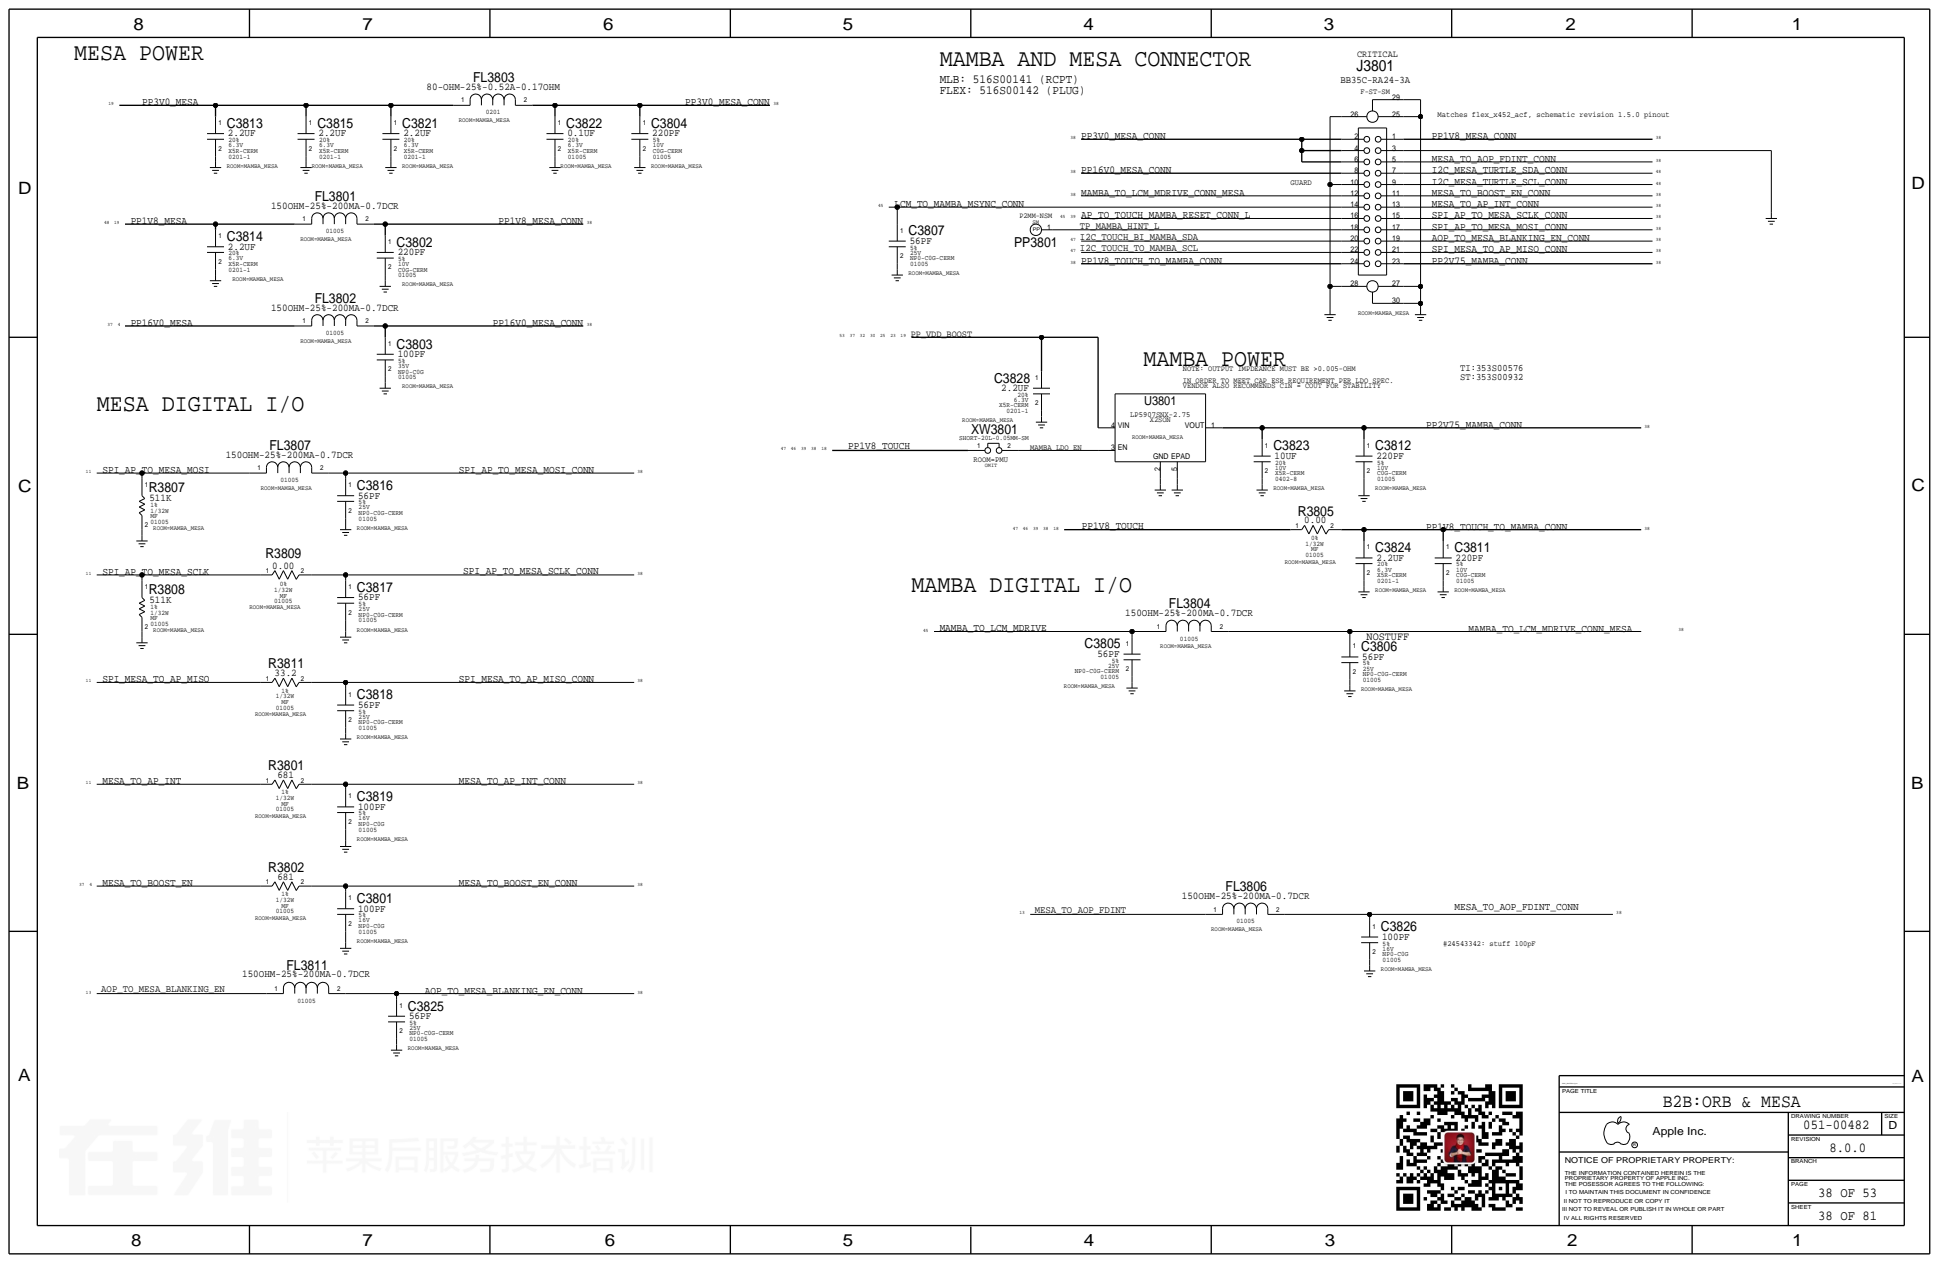
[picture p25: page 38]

MAMBA POWER
NOTE: OUTPUT IMPDEANCE MUST BE >0.005-OHM
IN ORDER TO MEET CAP ESR REQUIREMENT PER LDO SPEC.
VENDOR ALSO RECOMMENDS CIN = COUT FOR STABILITY

DISPLAY POWER | DISPLAY MIPI

# AP/TOUCH INTERFACE

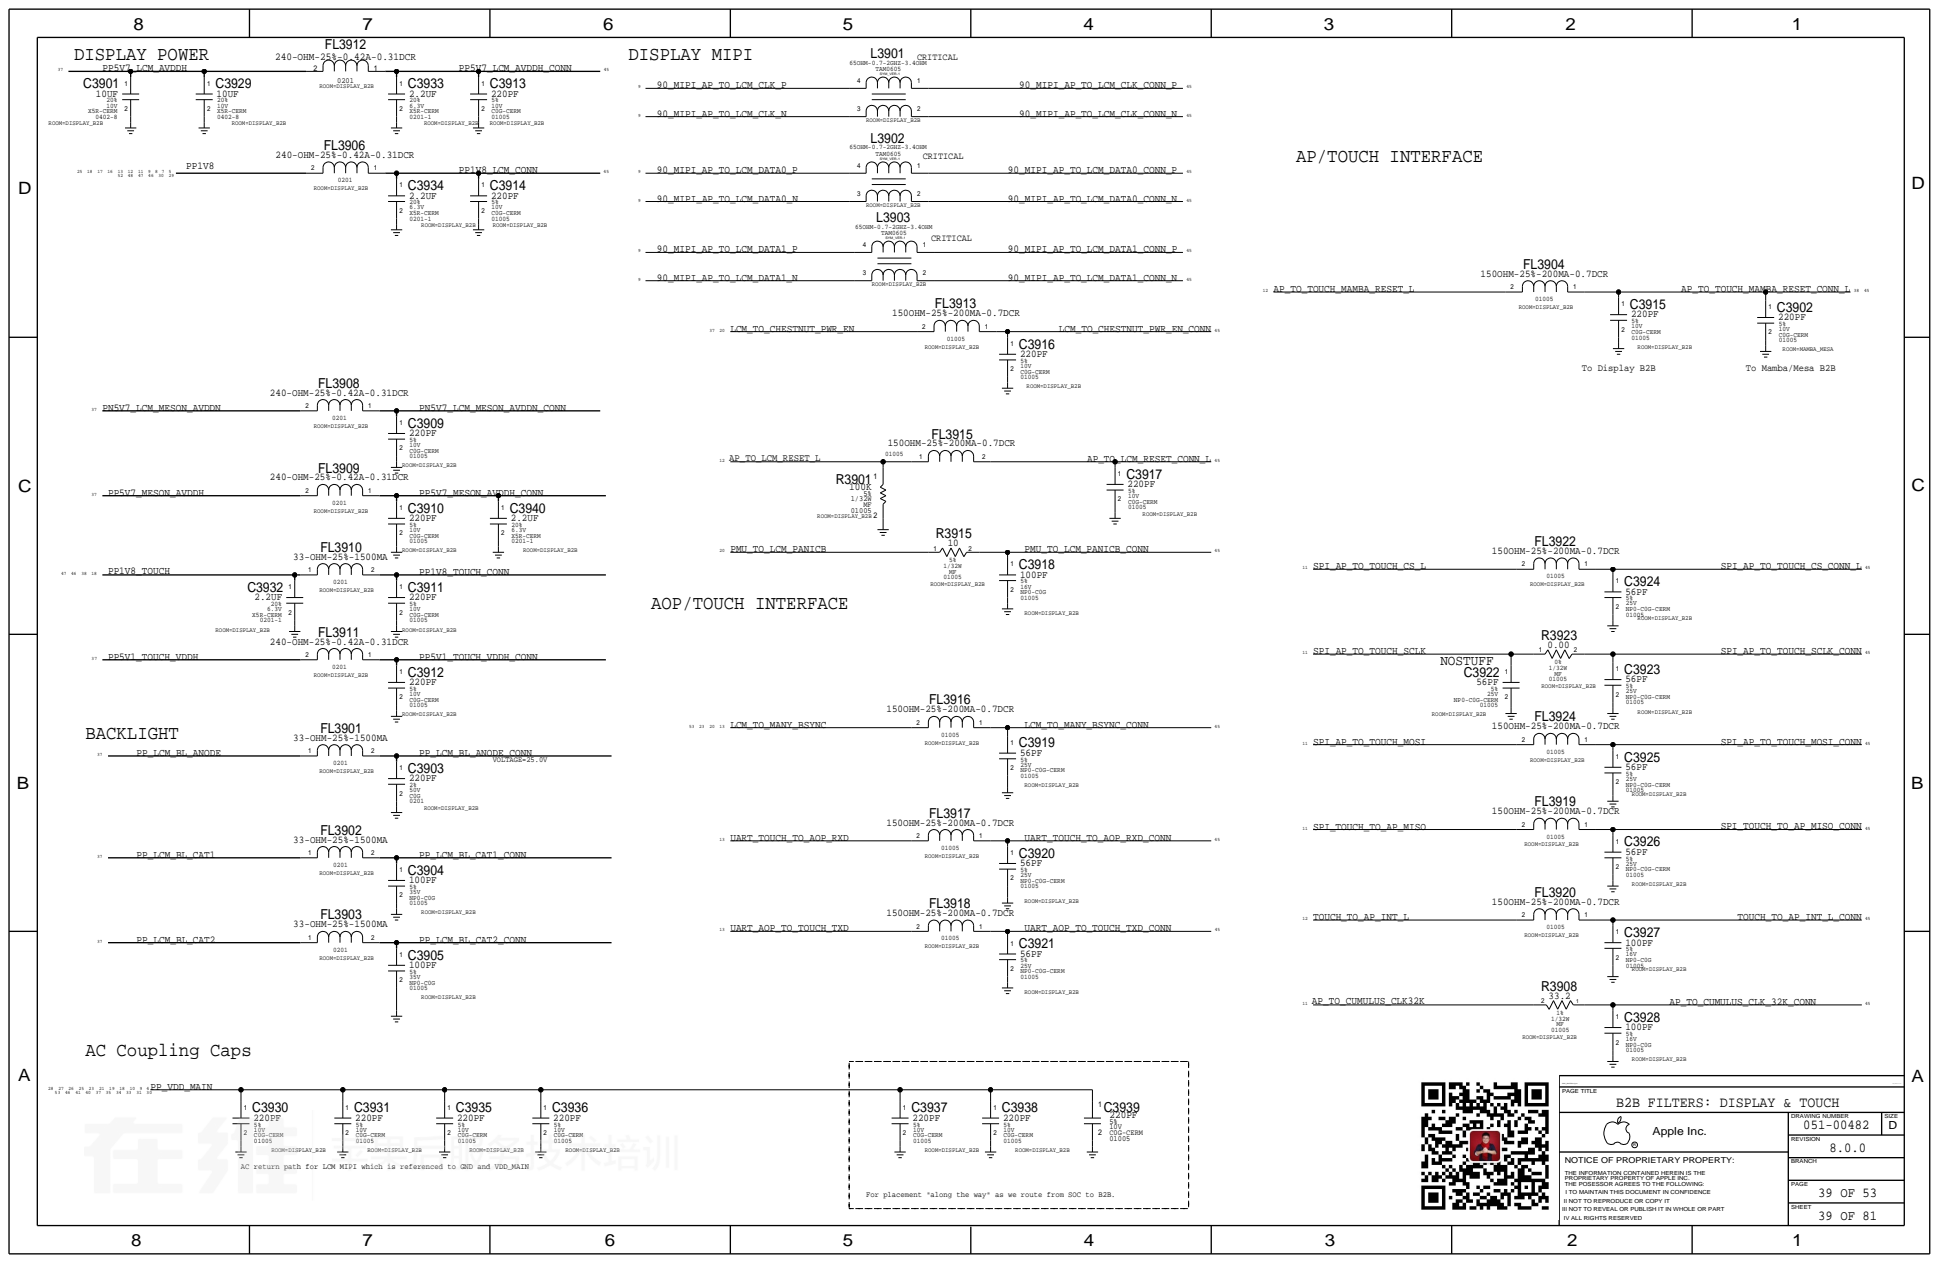
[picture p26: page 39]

For placement "along the way" as we route from SOC to B2B.
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

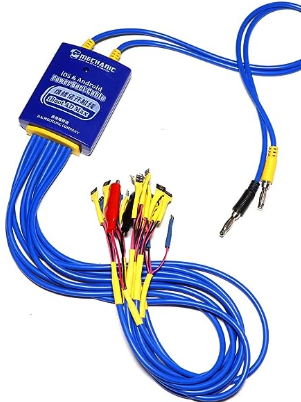
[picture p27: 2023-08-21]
dd.PNG
